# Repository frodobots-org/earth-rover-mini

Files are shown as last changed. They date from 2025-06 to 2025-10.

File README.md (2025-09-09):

<p align="center">
  Earth Rovers SDK Logo
  <h3 align="center">Frodobots AI</h3>
  <br>
</p>

# EarthRover Mini+

 

# Buy the Robot
- [Shopify](https://shop.frodobots.com/collections/earth-rovers/products/earth-rover-mini-plus)
  
# Getting Started

Core Development is done in two sections under Software
- [Software Development](/Software)
- [Host User Development](/Software/linux)
- [Client Side(EarthRover Mini) Development](/Software/STM32/applications)

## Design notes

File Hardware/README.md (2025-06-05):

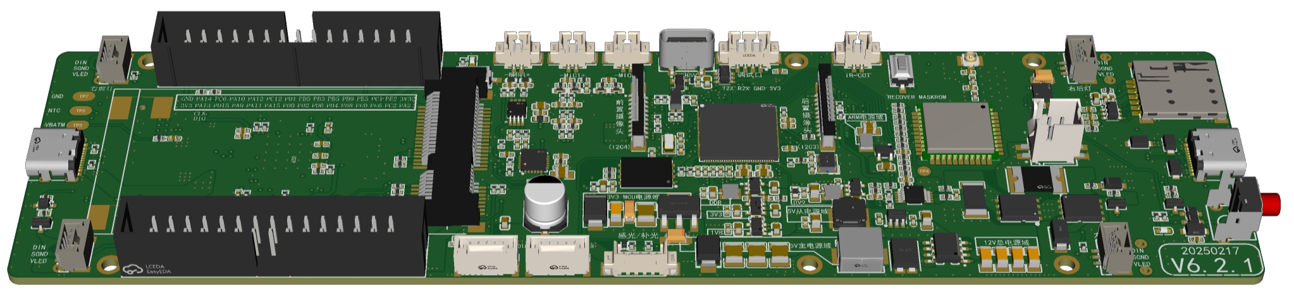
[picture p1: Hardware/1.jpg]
PCB1

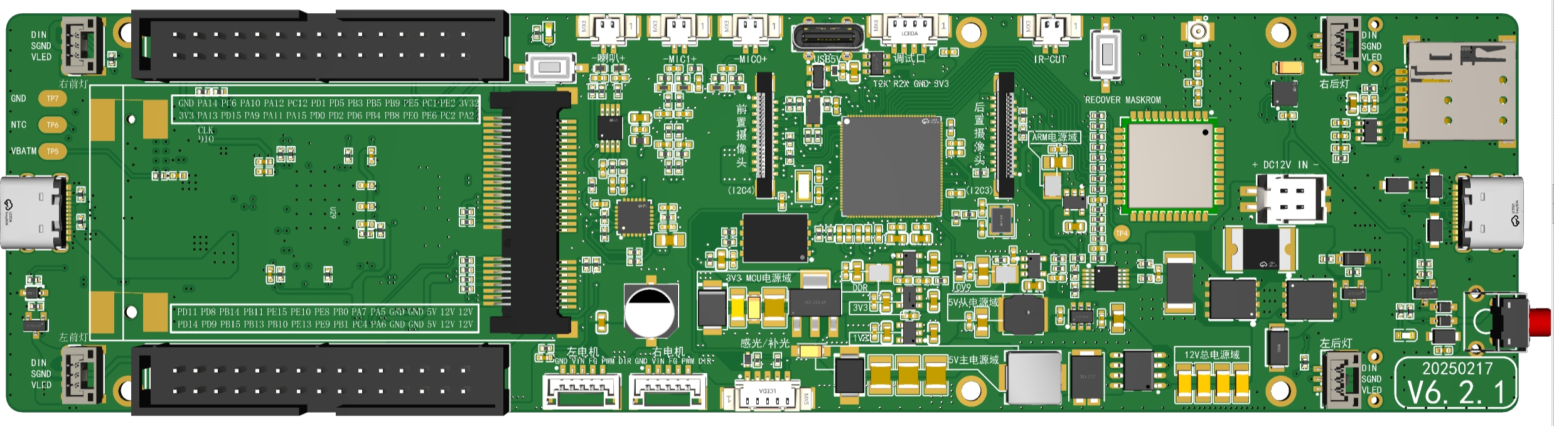
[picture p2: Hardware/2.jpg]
PCB2

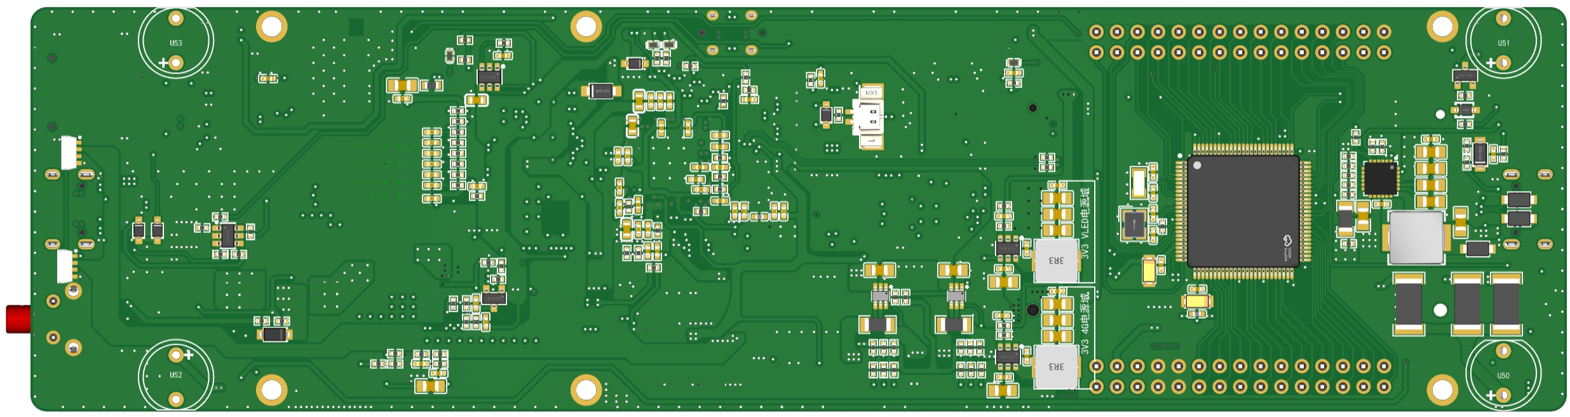
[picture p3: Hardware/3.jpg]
PCB3


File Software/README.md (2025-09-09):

# Specification
| | Specification |
|---|---|
| **Host** | RV1106G3 |
| **RAM (DDR)** | 256MB |
| **Flash (Nand)** | 128MB |
| **Operating System (Host)** | Linux |
| **Client** | STM32F407 |
| **Operating System (Client)** | RT-Thread |
| **Battery Type** | 18650 |
| **Battery Capacity** | 6000mAh |

# Block Diagram


# Core Architecture

The firmware is built on a **multi-threaded architecture**, where dedicated tasks handle specific subsystems.  
This concurrent design ensures that critical operations like **motor control** and **sensor processing** are not blocked by lower-priority tasks like communication.

The main threads are orchestrated in `applications/main.c`, which acts as the system's entry point.

## Key Threads

- **Main Thread (`main.c`)**  
  - Initializes all hardware peripherals and application threads.  
  - Enters a loop that manages system-level state (e.g., controlling LEDs for charging, running, error).

- **IMU Thread (`imu.c`)**  
  - Manages the Inertial Measurement Unit (MPU6050 + Magnetometer).  
  - Reads sensor data, performs sensor fusion, and handles calibration.

- **State Thread (`state.c`)**  
  - Handles robot power and operational logic.  
  - Monitors battery voltage/current, manages power sequences, and tracks system state.

- **Motor Thread (`motor.c`)**  
  - Translates desired speed/steering into PWM signals for motor drivers.

- **UART Threads (`uart_mutex.c`)**  
  - One thread listens for incoming commands.  
  - Another sends telemetry back to the host.

- **Control Loop Timer (`hwtimer.c`)**  
  - Provides a high-precision tick for the closed-loop motion control system.  
  - Runs PID calculations at a fixed rate.

---

# Important Files and Interactions

The system is divided into key modules that interact to achieve the robot’s functionality.

## 1. System Entry and State Management

- **`applications/main.c`**  
  - Initializes hardware, creates RTOS threads, and starts the scheduler.  
  - `main()`: Manages RGB status LEDs (charging, running, low battery).  

- **`applications/state.c`**  
  - Handles robot power state and operational mode.  
  - `state_thread_entry()`: Monitors battery (INA226), charger connection, and updates `robot_state`.  
  - `robot_power_on()` / `robot_power_off()`: Control physical power supply.  
  - `key_isr()` & `key_detect_task()`: Detect button presses and long-press events.

---

## 2. Motion Control and Closed-Loop Feedback

The motion control system integrates the **hardware timer**, **PID controller**, and **motor driver**.

- **`applications/hwtimer.c`**  
  - Provides timing for the PID loop.  
  - `timeout_cb()`: Executes every tick (e.g., 10 ms), computes motor RPM, and updates PID outputs.

- **`applications/pid.c`**  
  - Implements PID controllers for speed and heading.  
  - `get_Inc_pid_result()`: Incremental PID for speed (RPM adjustment).  
  - `get_heading_pid_result()`: PID for heading correction (yaw).

- **`applications/motor.c`**  
  - Interfaces control logic with physical motors.  
  - `motor_thread_entry()`: Main loop applying PID outputs.  
  - `motor_get_duty()`: Converts speed/steer commands to duty cycles.  
  - `motor_move_forward()`, `motor_move_backward()`, etc.: Handle motor direction and PWM updates.

---

## 3. Sensor Fusion and Orientation

The IMU subsystem provides stable orientation estimates using the MPU6050 and magnetometer.

- **`applications/imu.c`**  
  - `imu_thread_entry()`: Reads sensors, manages calibration, runs sensor fusion.  
  - `IMUupdate()` / `IMUupdate_dmp()`: Compute pitch, roll, and yaw.  
  - `MPU_6050_Calibrate()` / `QMC5883L_Calibrate()`: Handle calibration routines.

- **`applications/MPU6050_DMP/`**  
  - Contains InvenSense MPU6050 motion driver.  
  - `inv_mpu_dmp_motion_driver.c`: Loads/configures DMP firmware.  
  - `dmp_read_fifo()`: Reads quaternion data from FIFO.

---

## 4. Communication Protocol

External communication uses a **custom UART protocol (UCP)**.

- **`applications/ucp.h`**  
  - Defines UART Control Protocol (UCP).  
  - Contains command IDs (e.g., `UCP_MOTOR_CTL`, `UCP_RPM_REPORT`) and packet structures.

- **`applications/uart_mutex.c`**  
  - Implements thread-safe UART communication using mutexes.  
  - `uart_thread_entry()`: Receives and parses incoming data packets (CRC check, command handling).  
  - `uart_send_thread_entry()`: Periodically sends telemetry (RPM, battery, IMU orientation).  

---

# Development
- **Host**: 🖥 [Learn more here](../Software/Linux)
- **Client**: ⚙ [Learn more here](http://example.com/stm32f407)

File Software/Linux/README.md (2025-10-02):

# Earth Rover Mini+ Host Development

## Build Example
```
git clone --recursive https://github.com/frodobots-org/earth-rover-mini.git
cd earth-rover-mini/Software/Linux
mkdir build
cd build
cmake -DCMAKE_TOOLCHAIN_FILE=../toolchain.cmake ..
make
```

## Connect to Robot
- Install ADB on your development platform
- Search and connect the wireless network <b>frodobot_xxx</b>. The default password is <b>12345678</b>.
- Once the connection is established. Connect to your robot with adb
```bash
adb connect 192.168.11.1
adb shell
```

# Host Control Instructions

This section provides instructions on how to control the robot from a host computer for development and testing purposes.

---

## Control Mechanism

The robot is controlled via a **serial interface** using the custom **UART Control Protocol (UCP)** defined in `applications/ucp.h`.  
By sending formatted data packets to the robot's `uart3` port, you can:

- Control movement  
- Trigger calibration routines  
- Receive telemetry  

---

## Serial Port Settings

- **Baud Rate:** 115200  
- **Data Bits:** 8  
- **Parity:** None  
- **Stop Bits:** 1  

---

## Teleoperation (Manual Control)

To manually control the robot, send **`UCP_MOTOR_CTL` (ID: 0x02)** packets.  
These packets contain the desired **linear** and **angular velocity**.

---

## Control Packet Structure (`ucp_ctl_cmd_t`)

The command packet is composed of a **header**, a **payload**, and a **CRC checksum**.  
The **motor control payload** is defined as follows:

| Field | Type | Description |
|---|---|---|
| `hd` | `ucp_hd_t`| UCP Header (contains length, ID=0x02, index) |
| `speed` | `int16_t` | Desired linear velocity. Positive = forward, negative = backward. Range: -100 to 100. |
| `angular` | `int16_t` | Desired angular velocity. Positive = right, negative = left. Range: -100 to 100. |
| `front_led` | `int16_t` | Controls the front LEDs (not fully implemented). |
| `back_led`  | `int16_t` | Controls the back LEDs (not fully implemented). |
| `...` | `...` | Reserved fields. |

---

## Getting Started: A Simple Teleop Example

Look to `src/examples/move.cpp`

# Camera Example

## Getting Started: Dual Camera Streaming Over RTSP

Look to `src/Examples/sample_demo_dual_camera.c`
#### Run the example code on the Earth Rover Mini
- Build Examples
- Push `sample_demo_dual_camera` to device via ADB
```
adb push sample_demo_dual_camera /tmp/
```
- Run example
```
adb shell /tmp/sample_demo_dual_camera -s 0 -W 1920 -H 1080 -w 720 -h 576 -f 30 -r 0 -s 1 -W 1920 -H 1080 -w 720 -h 576 -f 30 -r 0 -n 1 -b 1
```
#### Capture video from the Earth Rover Mini camera on the computer
- Connect with Earth Rover Mini with same local network.
- Use Python Opencv
```python
import cv2
'''
rtsp://<Earth Rover Mini IP>/live/0  Front camera main-stream
rtsp://<Earth Rover Mini IP>/live/1  Front camera sub-stream
rtsp://<Earth Rover Mini IP>/live/2  Rear camera main-stream
rtsp://<Earth Rover Mini IP>/live/3  Rear camera sub-stream
'''
cap = cv2.VideoCapture("rtsp://<Earth Rover Mini IP>/live/0")
if not cap.isOpened():
    print("Failed to open RTSP stream")
    exit()
while True:
    ret, frame = cap.read()
    if not ret:
        print("Failed to read frame")
        break
    cv2.imshow("RTSP Stream", frame)
    if cv2.waitKey(1) & 0xFF == ord("q"):
        break

cap.release()
cv2.destroyAllWindows()
```

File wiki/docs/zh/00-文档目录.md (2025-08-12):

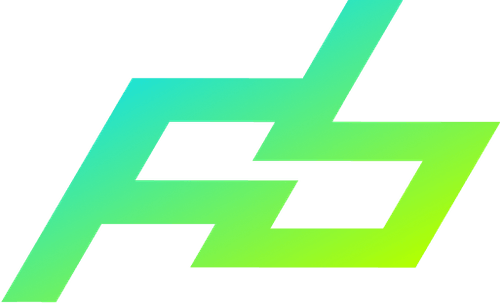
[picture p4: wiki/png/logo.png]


# 00-文档目录

## 1 组装与烧录

## 2 在Discord驾驶

## 3 登录机器

* adb 工具安装
* ssh 工具安装
* 通过adb访问机器
* 通过ssh访问机器 

## 4 在机器上运行程序

* 交叉编译
* 开机启动

## 5 STM32 功能开发

* **5.1 电机控制**
* **5.2 指示灯控制**
* **5.3 车灯控制**
* **5.4 电池容量**
* **5.5 IMU**
  * IMU 校准
  * IMU 数据获取

## 6 RV1106 功能开发

* **6.1 4G 模组入网与退网**
* **6.2 WIFI 模组入网与退网**
* **6.3 GPS 定位获取**
* **6.4  音视频媒体数据采集**
* **6.5 机器 web 页面**

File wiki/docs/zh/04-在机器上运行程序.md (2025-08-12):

# 04-在机器上运行程序

## 4.1 交叉编译

* 参考文档 [Readme](https://github.com/frodobots-org/earth-rover-mini/blob/dev/Software/Linux/README.md)

## 4.2 开启程序开机自启动

> 开发者可将/usr/bin/frodobot.bin 替换为自己编译后的程序

```shell
root@frodobot_j61grz:$ cat /usr/bin/frodobot.sh 
#!/bin/sh

#/usr/bin/frodobot-uart /dev/ttyS4

echo "frodobot-uart app exit."

while true; do
  /usr/bin/frodobot.bin
  echo "Exit frodobot. Sleep 5 sec..."
  sleep 5
done
```

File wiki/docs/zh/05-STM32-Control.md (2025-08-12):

# 05-STM32-Control
## 简介

* RV1106&STM32通信原理
RV1106与STM32的通信协议包构成为<hd><data><ccr>，以下是详细介绍：
* 协议头
```c
typedef struct ucp_hd {
    uint16_t    len; 
    uint8_t     id;
    uint8_t     index;
} ucp_hd_t __attribute__((packed));
```
RV1106&STM32的协议包头构成如上结构体的成员部分，<0xfd 0xff>、len-协议包字节长度、id-协议包id号、index-包序号，共6个字节长度。

* 协议尾
RV1106&STM32的协议包尾构成为CRC16校验位，共2个字节长度(CRC（循环冗余校验，Cyclic Redundancy Check）是一种常见的用于检测数据传输或存储错误的校验方式。它通过多项式运算，将数据映射为一个固定长度的校验码)，最终得到2个字节长度校验码<crc1 crc2>，以下代码块为两个校验查表数组以及校验算法部分。
```c
static uint8_t crc_hi_table [ ] = { 0x00 , 0xC1 , 0x81 , 0x40 , 0x01 , 0xC0 , 0x80 , 0x41 , 0x01 , 0xC0 , 0x80 , 0x41 ,
        0x00 , 0xC1 , 0x81 , 0x40 , 0x01 , 0xC0 , 0x80 , 0x41 , 0x00 , 0xC1 , 0x81 , 0x40 , 0x00 , 0xC1 , 0x81 ,
        0x40 , 0x01 , 0xC0 , 0x80 , 0x41 , 0x01 , 0xC0 , 0x80 , 0x41 , 0x00 , 0xC1 , 0x81 , 0x40 , 0x00 , 0xC1 ,
        0x81 , 0x40 , 0x01 , 0xC0 , 0x80 , 0x41 , 0x00 , 0xC1 , 0x81 , 0x40 , 0x01 , 0xC0 , 0x80 , 0x41 , 0x01 ,
        0xC0 , 0x80 , 0x41 , 0x00 , 0xC1 , 0x81 , 0x40 , 0x01 , 0xC0 , 0x80 , 0x41 , 0x00 , 0xC1 , 0x81 , 0x40 ,
        0x00 , 0xC1 , 0x81 , 0x40 , 0x01 , 0xC0 , 0x80 , 0x41 , 0x00 , 0xC1 , 0x81 , 0x40 , 0x01 , 0xC0 , 0x80 ,
        0x41 , 0x01 , 0xC0 , 0x80 , 0x41 , 0x00 , 0xC1 , 0x81 , 0x40 , 0x00 , 0xC1 , 0x81 , 0x40 , 0x01 , 0xC0 ,
        0x80 , 0x41 , 0x01 , 0xC0 , 0x80 , 0x41 , 0x00 , 0xC1 , 0x81 , 0x40 , 0x01 , 0xC0 , 0x80 , 0x41 , 0x00 ,
        0xC1 , 0x81 , 0x40 , 0x00 , 0xC1 , 0x81 , 0x40 , 0x01 , 0xC0 , 0x80 , 0x41 , 0x01 , 0xC0 , 0x80 , 0x41 ,
        0x00 , 0xC1 , 0x81 , 0x40 , 0x00 , 0xC1 , 0x81 , 0x40 , 0x01 , 0xC0 , 0x80 , 0x41 , 0x00 , 0xC1 , 0x81 ,
        0x40 , 0x01 , 0xC0 , 0x80 , 0x41 , 0x01 , 0xC0 , 0x80 , 0x41 , 0x00 , 0xC1 , 0x81 , 0x40 , 0x00 , 0xC1 ,
        0x81 , 0x40 , 0x01 , 0xC0 , 0x80 , 0x41 , 0x01 , 0xC0 , 0x80 , 0x41 , 0x00 , 0xC1 , 0x81 , 0x40 , 0x01 ,
        0xC0 , 0x80 , 0x41 , 0x00 , 0xC1 , 0x81 , 0x40 , 0x00 , 0xC1 , 0x81 , 0x40 , 0x01 , 0xC0 , 0x80 , 0x41 ,
        0x00 , 0xC1 , 0x81 , 0x40 , 0x01 , 0xC0 , 0x80 , 0x41 , 0x01 , 0xC0 , 0x80 , 0x41 , 0x00 , 0xC1 , 0x81 ,
        0x40 , 0x01 , 0xC0 , 0x80 , 0x41 , 0x00 , 0xC1 , 0x81 , 0x40 , 0x00 , 0xC1 , 0x81 , 0x40 , 0x01 , 0xC0 ,
        0x80 , 0x41 , 0x01 , 0xC0 , 0x80 , 0x41 , 0x00 , 0xC1 , 0x81 , 0x40 , 0x00 , 0xC1 , 0x81 , 0x40 , 0x01 ,
        0xC0 , 0x80 , 0x41 , 0x00 , 0xC1 , 0x81 , 0x40 , 0x01 , 0xC0 , 0x80 , 0x41 , 0x01 , 0xC0 , 0x80 , 0x41 ,
        0x00 , 0xC1 , 0x81 , 0x40 };

static uint8_t crc_lo_table [ ] = { 0x00 , 0xC0 , 0xC1 , 0x01 , 0xC3 , 0x03 , 0x02 , 0xC2 , 0xC6 , 0x06 , 0x07 , 0xC7 ,
        0x05 , 0xC5 , 0xC4 , 0x04 , 0xCC , 0x0C , 0x0D , 0xCD , 0x0F , 0xCF , 0xCE , 0x0E , 0x0A , 0xCA , 0xCB ,
        0x0B , 0xC9 , 0x09 , 0x08 , 0xC8 , 0xD8 , 0x18 , 0x19 , 0xD9 , 0x1B , 0xDB , 0xDA , 0x1A , 0x1E , 0xDE ,
        0xDF , 0x1F , 0xDD , 0x1D , 0x1C , 0xDC , 0x14 , 0xD4 , 0xD5 , 0x15 , 0xD7 , 0x17 , 0x16 , 0xD6 , 0xD2 ,
        0x12 , 0x13 , 0xD3 , 0x11 , 0xD1 , 0xD0 , 0x10 , 0xF0 , 0x30 , 0x31 , 0xF1 , 0x33 , 0xF3 , 0xF2 , 0x32 ,
        0x36 , 0xF6 , 0xF7 , 0x37 , 0xF5 , 0x35 , 0x34 , 0xF4 , 0x3C , 0xFC , 0xFD , 0x3D , 0xFF , 0x3F , 0x3E ,
        0xFE , 0xFA , 0x3A , 0x3B , 0xFB , 0x39 , 0xF9 , 0xF8 , 0x38 , 0x28 , 0xE8 , 0xE9 , 0x29 , 0xEB , 0x2B ,
        0x2A , 0xEA , 0xEE , 0x2E , 0x2F , 0xEF , 0x2D , 0xED , 0xEC , 0x2C , 0xE4 , 0x24 , 0x25 , 0xE5 , 0x27 ,
        0xE7 , 0xE6 , 0x26 , 0x22 , 0xE2 , 0xE3 , 0x23 , 0xE1 , 0x21 , 0x20 , 0xE0 , 0xA0 , 0x60 , 0x61 , 0xA1 ,
        0x63 , 0xA3 , 0xA2 , 0x62 , 0x66 , 0xA6 , 0xA7 , 0x67 , 0xA5 , 0x65 , 0x64 , 0xA4 , 0x6C , 0xAC , 0xAD ,
        0x6D , 0xAF , 0x6F , 0x6E , 0xAE , 0xAA , 0x6A , 0x6B , 0xAB , 0x69 , 0xA9 , 0xA8 , 0x68 , 0x78 , 0xB8 ,
        0xB9 , 0x79 , 0xBB , 0x7B , 0x7A , 0xBA , 0xBE , 0x7E , 0x7F , 0xBF , 0x7D , 0xBD , 0xBC , 0x7C , 0xB4 ,
        0x74 , 0x75 , 0xB5 , 0x77 , 0xB7 , 0xB6 , 0x76 , 0x72 , 0xB2 , 0xB3 , 0x73 , 0xB1 , 0x71 , 0x70 , 0xB0 ,
        0x50 , 0x90 , 0x91 , 0x51 , 0x93 , 0x53 , 0x52 , 0x92 , 0x96 , 0x56 , 0x57 , 0x97 , 0x55 , 0x95 , 0x94 ,
        0x54 , 0x9C , 0x5C , 0x5D , 0x9D , 0x5F , 0x9F , 0x9E , 0x5E , 0x5A , 0x9A , 0x9B , 0x5B , 0x99 , 0x59 ,
        0x58 , 0x98 , 0x88 , 0x48 , 0x49 , 0x89 , 0x4B , 0x8B , 0x8A , 0x4A , 0x4E , 0x8E , 0x8F , 0x4F , 0x8D ,
        0x4D , 0x4C , 0x8C , 0x44 , 0x84 , 0x85 , 0x45 , 0x87 , 0x47 , 0x46 , 0x86 , 0x82 , 0x42 , 0x43 , 0x83 ,
        0x41 , 0x81 , 0x80 , 0x40 };

static uint16_t crc16 ( char* msg , size_t len )
{
    uint8_t crc_hi = 0xFF;
    uint8_t crc_lo = 0xFF;
    uint8_t index;

    while ( len-- )
    {
        index = crc_lo ^ *msg++;
        crc_lo = crc_hi ^ crc_hi_table [ index ];
        crc_hi = crc_lo_table [ index ];
    }
    return (crc_hi << 8 | crc_lo);
}
```

* RV1106&STM32心跳包-01解析
RV1106可以通过ping包获取STM32的运行状态，以下是心跳包的组成结构
RV1106：
```c
typedef struct ucp_alive_ping {
    ucp_hd_t    hd;
} ucp_alive_ping_t __attribute__((packed));
```
RV1106的ping包组成十分简单，数据段部分是没有的，仅由一个包头包尾构成
ping包组成结构：<0xfd 0xff><hd><crc>

STM32：
```c
typedef struct ucp_alive_pong {
    ucp_hd_t    hd;
    uint8_t     err;
} ucp_alive_pong_t __attribute__((packed));
```
STM32的pong包组成相比RV1106的ping包的数据段多了一个错误码，以此反映STM32的运行状态，当错误码err = 0时，代表通信正常，err = 1则通信异常
pong包组成结构：<0xfd 0xff><hd><err><crc>

## 5.1 电机&车灯
* RV1106&STM32-控制协议包-02解析
RV1106：
```c
typedef struct ucp_ctl_cmd {
    ucp_hd_t    hd;
    int16_t     speed;
    int16_t     angular;
    int16_t     front_led;
    int16_t     back_led;
    uint16_t    version;
    uint16_t    reserve1;
    uint32_t    reserve2;
} ucp_ctl_cmd_t __attribute__((packed));
```
hd -> 包头（len-协议包字节长度、id-协议包id号、index-包序号）
speed -> 前进速度（speed > 0向前运动，speed < 0 向后运动，speed取值范围（-100 ~ 100））
angular-> 左右轮速差（angluar > 0向左运动，angluar < 0 向右运动，angluar取值范围（-100 ~ 100））
front_led-> 灯光控制（front_led = 100为开灯状态，front_led = 0为关灯状态）
back_led -> 保留位，暂不使用
version  -> 保留位，暂不使用
reserve1-> 保留位，暂不使用
reserve2 -> 保留位，暂不使用

* 电机控制
协议包组成：<0xfd 0xff><hd><speed><angular><......><crc>

* 车灯控制
协议包组成：<0xfd 0xff><hd><......><front_led><......><crc>

## 5.2 系统状态灯
* RV1106&STM32-状态灯控制协议包-0A解析
RV1106：
```c
typedef struct ucp_led_status {
    ucp_hd_t    hd;
    ucp_state_e status;
}
```
hd-> 包头（len-协议包字节长度、id-协议包id号、index-包序号）
status-> RV1106联网状态（详细见以下枚举）

```c
typedef enum ucp_state_e {
        UCP_STATE_UNKNOWN = 0,       //初始状态
        UCP_STATE_SIMABSENT = 1,     //SIM检测中 
        UCP_NETWORK_DISCONNECTED,    //联网失败
        UCP_NETWORK_CONNECTED,       //联网成功
} ucp_state_e;
```
* 状态灯控制
状态灯控制协议包组成结构：<0xfd 0xff><hd><status><crc>
## 5.4 系统电源
* RV1106&STM32-回传协议包-05解析
该协议包STM32自动上报RV1106,每20ms发送一包
STM32：
```c
typedef struct ucp_rep { //report
    ucp_hd_t    hd;
    uint16_t    battery;
    int16_t     rpm[4];
    uint8_t     power;
    uint8_t     voltage;
    uint16_t    current;
    int16_t     acc[3];
    int16_t     gyros[3];
    int16_t     mag[3];
    int16_t     heading;
} ucp_rep_t __attribute__((packed));
```
hd              -> 包头（len-协议包字节长度、id-协议包id号、index-包序号）
battery         -> 电池电量百分比（battery取值范围（-100 ~ 100））
power           -> 系统功率（W）
voltage         -> 系统电压（10 * V）
current         -> 系统电流（100 * A）

* 电源数据读取示例
## 5.5 IMU
### 5.5.1 IMU校准
* RV1106&STM32-IMU校准协议包-03解析

* RV1106&STM32-IMU校准协议包-04解析

### 5.5.2 IMU数据获取
* RV1106&STM32-回传协议包-05解析

### 5.5.3 保存校准数据
* RV1106&STM32-IMU校准回传协议包-06解析

* RV1106&STM32-IMU校准回传协议包-07解析

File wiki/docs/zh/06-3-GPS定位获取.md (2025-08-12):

# 06-3 GPS定位获取

**Miniplus GPS 模组使用 Quectel LC29HDA, 支持双频、RTK解算、开阔环境精度达到厘米级别**

> 室内以及遮挡严重区域无法获得GPS定位

## 1 LC29H GPS 模组

* 串口波特率 115200
* 串口输入输出语句符合 [NMEA0183 ](https://en.wikipedia.org/wiki/NMEA_0183)格式

## 2 打开GPS输出

* NMEA1083 语句校验

  ```c++
  #include <ostream>
  #include <iostream>
  #include <iomanip>
  #include <sstream>
  
  static unsigned char calculateChecksum(const std::string& sentence) {
      unsigned char checksum = 0;
      for (size_t i = 1; i < sentence.size() && sentence[i] != '*'; ++i) {
          checksum ^= sentence[i];
      }
      return checksum;
  }
  
  static std::string constructNMEASentence(const std::string& baseSentence) {
      unsigned char checksum = calculateChecksum(baseSentence);
      std::ostringstream oss;
      oss << baseSentence << '*' << std::uppercase << std::hex << std::setw(2) << std::setfill('0') << static_cast<int>(checksum) << "\r\n";
      return oss.str();
  }
  ```

* 设置GPS语句输出频率

  ```c++
  int lc29h::Init()
  {
          if (!this->Probe()) { //探测串口设备是否存在
                  std::cout << "Probe failed.\n";
                  return -1;
          }
  
          this->Open(); //打开串口设备
  
          this->Write(constructNMEASentence("$PQTMVERNO")); //查询版本号
          std::string line;
          this->Read(line);
          if (line.empty()) {
                  SPDLOG_WARN("LC29H is not exsit.");
                  return -1;
          }
  
          SPDLOG_INFO("LC29H Version {} ", line);
  
      	//输出频率最高支持20HZ
          this->Write(constructNMEASentence("$PQTMCFGMSGRATE,W,GSV,1")); //以1HZ 频率输出GSV语句
          this->Write(constructNMEASentence("$PQTMCFGMSGRATE,W,RMC,1")); //以1HZ 频率输出RMC语句
          this->Write(constructNMEASentence("$PQTMCFGMSGRATE,W,GSA,0")); //关闭GSA语句输出
          this->Write(constructNMEASentence("$PQTMCFGMSGRATE,W,GLL,0")); //关闭GLL语句输出
          this->Write(constructNMEASentence("$PQTMCFGMSGRATE,W,VTG,0")); //关闭VTG语句输出
          this->Write(constructNMEASentence("$PQTMCFGMSGRATE,W,GGA,1")); //以1HZ 频率输出GGA语句
  
          std::cout << "lc29h Init done." << std::endl;
          exit_ = false;
  
          return 0;
  }
  ```

## 2 解析GPS语句

**串口输入输出语句符合 [NMEA0183 ](https://en.wikipedia.org/wiki/NMEA_0183)格式, 可使用开源库[minmea](https://github.com/kosma/minmea) 解析NMEA0183语句, 读取串口以获取GPS定位语句**

```c++
void Ec2x::ParseNmeaSentence(std::string sentence) {
        static float rmc_speed = 0;
        static int rmc_ttff = 0;
        static bool last_sentence_is_gsv = false;
        switch(minmea_sentence_id(sentence.c_str(), false)) {
        case MINMEA_SENTENCE_GGA: {
                struct minmea_sentence_gga frame;
                if (minmea_parse_gga(&frame, sentence.c_str())) {
                        float longitude = minmea_tocoord(&frame.longitude);
                        float latitude = minmea_tocoord(&frame.latitude);
                        float hdop = minmea_tocoord(&frame.hdop);
                        float altitude = minmea_tocoord(&frame.altitude);
                        //SPDLOG_INFO("longitude {} latitude {} hdop {} altitude {} fix_quality {}",ongitude, latitude, hdop, altitude, frame.fix_quality);
                }
        } break;
        default: {
        } break;
        }
}
```

## 3 使用RTK服务实现厘米级定位

**LC29HDA模组支持直接输入RTCM3语句辅助GPS位置解算，提高定位精度**

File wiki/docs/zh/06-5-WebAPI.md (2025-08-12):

# 06-5 Web API

**机器提供系列HTTP API 做访问及控制**

### 1 4G入网配置

### 2 WIFI入网配置

### 3 流媒体配置

### 4 电机控制

### 5 IMU 矫正及数据收集

### 6 GPS数据收集

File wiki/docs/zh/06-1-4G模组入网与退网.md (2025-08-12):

# 06-1 4G模组入网与退网

1. **检查模组插入状态**

   1. 开机过程中出现或者输入 dmesg 指令查看，出现下方日志证明4G模组正确插入

      ```shell
      [  378.744099] usb 1-1.1: new high-speed USB device number 5 using xhci-hcd
      [  378.913481] option 1-1.1:1.0: GSM modem (1-port) converter detected
      [  378.914580] usb 1-1.1: GSM modem (1-port) converter now attached to ttyUSB0
      [  378.915026] option 1-1.1:1.1: GSM modem (1-port) converter detected
      [  378.916713] usb 1-1.1: GSM modem (1-port) converter now attached to ttyUSB1
      [  378.917208] option 1-1.1:1.2: GSM modem (1-port) converter detected
      [  378.918934] usb 1-1.1: GSM modem (1-port) converter now attached to ttyUSB2
      [  378.919423] option 1-1.1:1.3: GSM modem (1-port) converter detected
      [  378.921144] usb 1-1.1: GSM modem (1-port) converter now attached to ttyUSB3
      [  378.945926] qmi_wwan_q 1-1.1:1.4: cdc-wdm0: USB WDM device
      [  378.947713] qmi_wwan_q 1-1.1:1.4: Quectel EG25-G work on RawIP mode
      [  378.948779] qmi_wwan_q 1-1.1:1.4: rx_urb_size = 1520
      [  378.949272] qmi_wwan_q 1-1.1:1.4 wwan0: register 'qmi_wwan_q' at usb-xhci-hcd.0.auto-1.1, WWAN/QMI device, a6:02:08:ff:40:7d
      ```

   2. 出现下方日志证明4G模组被中途拔出，需要检查。

      ```shell
      [  364.896693] usb 1-1.1: USB disconnect, device number 4
      [  364.897175] option1 ttyUSB0: GSM modem (1-port) converter now disconnected from ttyUSB0
      [  364.897251] option 1-1.1:1.0: device disconnected
      [  364.899374] option1 ttyUSB1: GSM modem (1-port) converter now disconnected from ttyUSB1
      [  364.899462] option 1-1.1:1.1: device disconnected
      [  364.899932] option1 ttyUSB2: GSM modem (1-port) converter now disconnected from ttyUSB2
      [  364.900006] option 1-1.1:1.2: device disconnected
      [  364.900819] option1 ttyUSB3: GSM modem (1-port) converter now disconnected from ttyUSB3
      [  364.900908] option 1-1.1:1.3: device disconnected
      [  364.901168] qmi_wwan_q 1-1.1:1.4 wwan0: unregister 'qmi_wwan_q' usb-xhci-hcd.0.auto-1.1, WWAN/QMI device
      ```

   3. 运行过程中出现下列日志说明4G模组未正确插入。

      ```shell
      [06-23_07:12:26:076] Quectel_QConnectManager_Linux_V1.6.0.24
      [06-23_07:12:26:078] network interface '' or qmidev '' is not exist
      [06-23_07:12:26:078] qmidevice_detect failed
      [06-23_07:12:26:078] qmidevice_detect failed
      ```

2. **注网程序**

   > quectel-CM 是移远官方提供用来拨号注网的程序，系统会自动运行拨号程序，如果需要手动尝试，请先停止掉启动脚本和quectel-CM拨号程序

   1. 自启动脚本

      > quectel.sh 自启动脚本用做参数化开机启动和保活quectel-CM 入网程序

      ```shell
      root@frodobot_j61grz:$ cat /usr/bin/quectel.sh 
      #!/bin/sh
      
      while true; do
        ARGS=$(cat /userdata/lte.env)
        /usr/bin/quectel-CM $ARGS
        sleep 5
      done
      ```

   2. quectel-CM 参数介绍

      > 通常在国内无需设置任何运行参数，直接运行quectel-CM 进程即可。

      ```shell
      [06-23_04:32:27:609] Quectel_QConnectManager_Linux_V1.6.0.24
      [06-23_04:32:27:609] Usage: quectel-CM [options]
      [06-23_04:32:27:609] -s [apn [user password auth]]          Set apn/user/password/auth get from your network provider. auth: 1~pap, 2~chap
      [06-23_04:32:27:609] -p pincode                             Verify sim card pin if sim card is locked
      [06-23_04:32:27:609] -p [quectel-][qmi|mbim]-proxy          Request to use proxy
      [06-23_04:32:27:609] -f logfilename                         Save log message of this program to file
      [06-23_04:32:27:609] -u usbmonlog filename                  Save usbmon log to file
      [06-23_04:32:27:609] -i interface                           Specify which network interface to setup data call when multi-modems exits
      [06-23_04:32:27:609] -4                                     Setup IPv4 data call (default)
      [06-23_04:32:27:609] -6                                     Setup IPv6 data call
      [06-23_04:32:27:609] -n pdn                                 Specify which pdn to setup data call (default 1 for QMI, 0 for MBIM)
      [06-23_04:32:27:609] -k pdn                                 Specify which pdn to hangup data call (by send SIGINT to 'quectel-CM -n pdn')
      [06-23_04:32:27:609] -m iface-idx                           Bind QMI data call to wwan0_<iface idx> when QMAP used. E.g '-n 7 -m 1' bind pdn-7 data call to wwan0_1
      [06-23_04:32:27:609] -b                                     Enable network interface bridge function (default 0)
      [06-23_04:32:27:609] -v                                     Verbose log mode, for debug purpose.
      [06-23_04:32:27:609] [Examples]
      [06-23_04:32:27:610] Example 1: quectel-CM 
      [06-23_04:32:27:610] Example 2: quectel-CM -s 3gnet 
      [06-23_04:32:27:610] Example 3: quectel-CM -s 3gnet carl 1234 1 -p 1234 -f gobinet_log.txt
      ```

   3. SIM卡插入状态

      1. SIM 卡未插入 (SIMStatus : SIM_ABSENT)

         ```shell
         [01-01_15:09:17:488] Get clientWDS = 17
         [01-01_15:09:17:531] Get clientDMS = 1
         [01-01_15:09:17:554] Get clientNAS = 2
         [01-01_15:09:17:581] Get clientUIM = 2
         [01-01_15:09:17:620] Get clientWDA = 1
         [01-01_15:09:17:649] requestBaseBandVersion EG25GGBR07A08M2G
         [01-01_15:09:17:779] requestGetSIMStatus SIMStatus: SIM_ABSENT
         [01-01_15:09:17:808] requestGetProfile[1] CTNET///0
         [01-01_15:09:17:848] requestRegistrationState2 MCC: 0, MNC: 0, PS: Detached, DataCap: UNKNOW
         [01-01_15:09:17:869] requestQueryDataCall IPv4ConnectionStatus: DISCONNECTED
         [01-01_15:09:17:869] ifconfig wwan0 0.0.0.0
         [01-01_15:09:17:908] ifconfig wwan0 down
         ```

      2. SIM卡插入，拨号入网成功

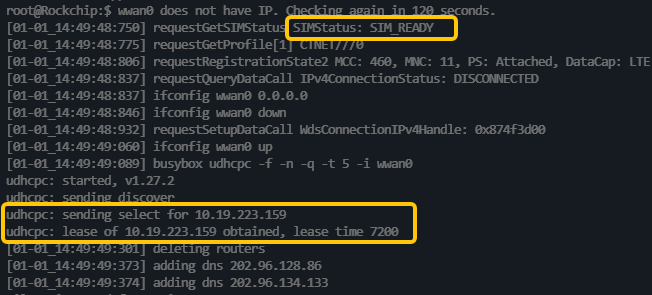
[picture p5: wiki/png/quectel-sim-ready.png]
         

         > **注意如果拨号成功仍然不能上网（使用ping 命令测试联网结果），则可能是SIM卡欠费或者流量异常。

         ``` shell
         ping frodobots.ai
         ```

   4. 查看联网状态

      * p2p0 为机器热点的固定IP地址。
      * wlan0 是机器的WIFI 网卡，成功连接路由器后在inet addr 一栏会得到一个点分十进制的局域网IP地址。
      * wwan0 是4G网卡，成功连接基站后在inet addr 一栏会得到一个点分十进制的局域网IP地址。

      ```shell
      root@frodobot_j61grz:$ ifconfig
      lo        Link encap:Local Loopback  
                inet addr:127.0.0.1  Mask:255.0.0.0
                UP LOOPBACK RUNNING  MTU:65536  Metric:1
                RX packets:0 errors:0 dropped:0 overruns:0 frame:0
                TX packets:0 errors:0 dropped:0 overruns:0 carrier:0
                collisions:0 txqueuelen:1000 
                RX bytes:0 (0.0 B)  TX bytes:0 (0.0 B)
      
      p2p0      Link encap:Ethernet  HWaddr A6:E8:8D:D9:9B:26  
                inet addr:192.168.11.1  Bcast:192.168.11.255  Mask:255.255.255.0
                UP BROADCAST RUNNING MULTICAST  MTU:1500  Metric:1
                RX packets:0 errors:0 dropped:0 overruns:0 frame:0
                TX packets:0 errors:0 dropped:0 overruns:0 carrier:0
                collisions:0 txqueuelen:1000 
                RX bytes:0 (0.0 B)  TX bytes:0 (0.0 B)
      
      wlan0     Link encap:Ethernet  HWaddr A4:E8:8D:D9:9B:26  
                inet addr:192.168.1.41  Bcast:192.168.1.255  Mask:255.255.255.0
                UP BROADCAST MULTICAST  MTU:1500  Metric:1
                RX packets:1323 errors:0 dropped:790 overruns:0 frame:0
                TX packets:95 errors:0 dropped:0 overruns:0 carrier:0
                collisions:0 txqueuelen:1000 
                RX bytes:190031 (185.5 KiB)  TX bytes:24235 (23.6 KiB)
      
      wwan0     Link encap:Ethernet  HWaddr A6:02:08:FF:40:7D  
                inet addr:10.7.189.65  Mask:255.255.255.252
                UP RUNNING NOARP  MTU:1500  Metric:1
                RX packets:2 errors:0 dropped:0 overruns:0 frame:0
                TX packets:2 errors:0 dropped:0 overruns:0 carrier:0
                collisions:0 txqueuelen:1000 
                RX bytes:612 (612.0 B)  TX bytes:656 (656.0 B)
      ```

3. 退网

   > 输入指令

   ```shell
   killall quectel.sh && killall quectel-CM
   或者是
   killall quectel.sh && ifconfig wwan0 down
   ```

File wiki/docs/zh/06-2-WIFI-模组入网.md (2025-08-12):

# 06-2 WIFI 模组入网

## 1  使用机器网页配网

* 手机连接机器热点(名称为 frodobot_xx)
* 打开手机浏览器进入网页 192.168.11.1

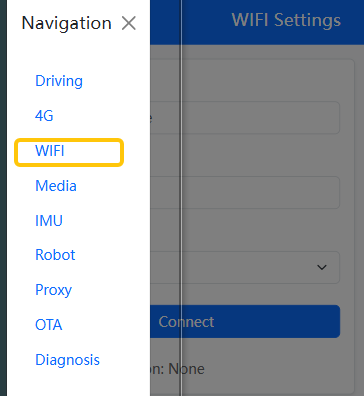
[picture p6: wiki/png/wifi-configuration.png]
	

* 输入SSID 和 PSK , 点击连接，15秒内应该建立WIFI连接

  > 如果是开放式WIFI，无需填写密码, Security Type 选择NONE

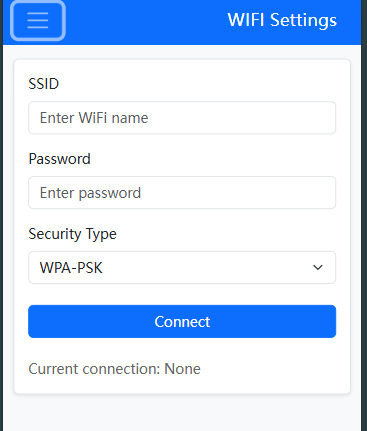
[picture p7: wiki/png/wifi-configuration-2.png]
	

## 2  手动修改WIFI 配置使用wpa_supplicant 工具配网

* 编辑配置文件

```shell
root@frodobot_j61grz:$ cat /userdata/wpa_supplicant.conf 
ctrl_interface=/var/run/wpa_supplicant
update_config=1
network={
    ssid="Frodobots"
    psk="11223344"
    key_mgmt=WPA-PSK
}
//如果是开放式WIFI, 密码不需要填写，key_mgmt=NONE
```

* 使用wpa_supplicant 工具连接WIFI

  > 连接前确保wpa_supplicant 进程没有在后台运行，如果有需要先停止掉wpa_supplicant 进程

```shell
killall wpa_supplicant
wpa_supplicant -B -iwlan0 -c /userdata/wpa_supplicant.conf
```

```shell
root@frodobot_j61grz:$ wpa_supplicant -B -iwlan0 -c /userdata/wpa_supplicant.con
f
Successfully initialized wpa_supplicant
rfkill: Cannot open RFKILL control device
root@frodobot_j61grz:$ wwan0 does not have IP. Checking again in 120 seconds.
[ 2301.645190] RTW: wlan0- hw port(1) mac_addr =a4:e8:8d:d9:9b:26
[ 2301.645471] RTW: p2p0- hw port(0) mac_addr =a6:e8:8d:d9:9b:26
[ 2301.661688] ========== ACS (VER-3) ==========
[ 2301.661715] Best 24G Channel:9
[ 2301.661728] Best 5G Channel:52
[ 2301.661728] 
[ 2301.669197] RTW: rtw_set_802_11_connect(wlan0)  fw_state=0x00000008
[ 2301.881953] RTW: start auth
[ 2301.885685] RTW: auth success, start assoc
[ 2301.904620] RTW: assoc success
[ 2301.910577] RTW: ============ STA [68:1b:ef:55:2a:20]  ===================
[ 2301.910618] RTW: mac_id : 2
[ 2301.910637] RTW: wireless_mode : 0x23
[ 2301.910655] RTW: mimo_type : 0
[ 2301.910672] RTW: static smps : N
[ 2301.910692] RTW: bw_mode : 20MHz, ra_bw_mode : 20MHz
[ 2301.910711] RTW: rate_id : 18
[ 2301.910730] RTW: rssi : -1 (%), rssi_level : 0
[ 2301.910750] RTW: is_support_sgi : Y, is_vht_enable : Y
[ 2301.910770] RTW: disable_ra : N, disable_pt : N
[ 2301.910788] RTW: is_noisy : N
[ 2301.910804] RTW: txrx_state : 0
[ 2301.910823] RTW: curr_tx_rate : CCK_1M (L)
[ 2301.910841] RTW: curr_tx_bw : 20MHz
[ 2301.910858] RTW: curr_retry_ratio : 0
[ 2301.910875] RTW: ra_mask : 0x00000000003fffff
[ 2301.910875] 
[ 2301.974511] RTW: recv eapol packet 1/4
[ 2301.976197] RTW: send eapol packet 2/4
[ 2302.015994] RTW: recv eapol packet 3/4
[ 2302.017327] RTW: send eapol packet 4/4
[ 2302.019276] RTW: set pairwise key camid:2, addr:68:1b:ef:55:2a:20, kid:0, type:AES
[ 2302.023181] RTW: set group key camid:3, addr:68:1b:ef:55:2a:20, kid:2, type:AES
```

* 使用udhcpc 工具获取IP地址

```shell
udhcpc -i wlan0
```

```shell
root@frodobot_j61grz:$ udhcpc -i wlan0
udhcpc: started, v1.27.2
udhcpc: sending discover

udhcpc: sending select for 192.168.1.41
udhcpc: lease of 192.168.1.41 obtained, lease time 259200
deleting routers
adding dns 192.168.1.1
```

## 3  断开WIFI网络

* 方式1 停止WIFI网卡

  ```shell
  ifconfig wlan0 down
  ```

* 方式2 输入一个错误的WIFI账号

* 方式3 停止wpa_supplicant 进程

  ```shell
  killall wpa_supplicant
  ```

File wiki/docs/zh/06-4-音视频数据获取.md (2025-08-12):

# 06-4 音视频数据获取

**机器提供HTTP API 来开启RTSP-Server 为客户端提供实时流媒体**

**基础信息**

- 接口域名：`http(s)://192.168.11.1/rtsp`
- 请求方式：POST
- 数据格式：JSON
- 认证方式：账户密码（HTTP Basic Auth）

## 1 开启RTSP流

> 接口URL

```shell
/start
```

**请求参数**

| 参数名 | 类型 | 是否必填 | 描述 |
| --- | --- | --- | --- |
| stream_id  | String | 是 | 流 ID，唯一标识 |
| resolution | String | 否 | 分辨率（如 "1080p"） |
| framerate  | Int | 否 | 帧率（默认 25） |
| bitrate | Int | 否 | 码率（Kbps） |

**请求示例**

```shell
curl -X POST \
  -u "username:password" \
  -H "Content-Type: application/json" \
  -d '{
    "stream_id": "camera001",
    "resolution": "720p",
    "framerate": 30,
    "bitrate": 2000
  }' \
  https://192.168.11.1/rtsp/start
```

**返回参数**

| 参数名 | 类型 | 描述 |
| --- | --- | --- |
| code | Int | 状态码（200 成功） |
| message | String | 提示信息 |
| rtsp_url  | String | RTSP 流地址 |
| expire_at | String | 流有效期（ISO 格式） |

**返回示例（成功）**

```json
{
  "code": 200,
  "message": "RTSP stream started successfully",
  "rtsp_url": "rtsp://192.168.11.1:554/camera001",
  "expire_at": "2025-06-24T12:00:00Z"
}
```

**返回示例（失败）**

```json
{
  "code": 401,
  "message": "Authentication failed"
}
```

## 2 关闭 RTSP 流

**接口 URL**

```plaintext
/stop
```

**请求参数**

| 参数名 | 类型 | 是否必填 | 描述 |
| --- | --- | --- | --- |
| stream_id | String | 是 | 流 ID，需关闭 |

**请求示例**

```shell
curl -X POST \
  -u "username:password" \
  -H "Content-Type: application/json" \
  -d '{
    "stream_id": "camera001"
  }' \
  https://api.example.com/rtsp/stop
```

**返回参数**

| 参数名  | 类型 | 描述 |
| --- | --- | --- |
| code | Int | 状态码（200 成功） |
| message | String | 提示信息 |

**返回示例（成功）**

```json
{
  "code": 200,
  "message": "RTSP stream stopped successfully"
}
```

## 3 错误码说明

| 错误码 | 描述 | 原因 |
| --- | --- | --- |
| 400 | Bad Request | 参数格式错误 |
| 401 | Unauthorized | 认证失败（账户 / 密码错误） |
| 403 | Forbidden | 权限不足 |
| 404 | Not Found | 流 ID 不存在 |
| 500 | Internal Server Error | 服务器内部错误 |

## 4 认证说明

- **方式**：HTTP Basic Authentication
- **示例**：在请求头中添加 `Authorization: Basic base64(username:password)`
- **生成工具**：可使用在线 Base64 编码工具生成认证头

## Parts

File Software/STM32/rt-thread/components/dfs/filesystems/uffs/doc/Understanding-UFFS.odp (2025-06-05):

## Understanding UFFS

Ricky Zheng

< ricky_gz_zheng@yahoo.co.nz >

Created: March 2007

Last modified: Nov 2011

## Content

- Why UFFS ?
- Design goal
- Flash: NOR vs NAND ?
- What's wrong with FAT ?
- UFFS basic idea
  - Serial number
  - Tree in memory
  - Journalizing
- UFFS architecture
  - UFFS device
  - Mount point
  - UFFS nodes tree
  - Mounting UFFS
  - Page spare/UFFS tags
  - Block info cache
  - UFFS page buffer
  - Block recover
  - Bad block management
  - How ECC works ?
  - Flash interface
- What's next ?
  - UFFS2

## Why UFFS ?

- JFFS/JFFS2
  - Can't go out of Linux/MTD
  - Memory monster
- YAFFS/YAFFS2 still consumes too much RAM
  - 64M FLASH, 500 files ==> 410K RAM
- No open source lightweight flash file system exists yet ...

## UFFS design goal

- Ultra low cost
  - Low memory cost
  - Fast booting
- Superb Stability
  - Constant RAM consumption, support static memory allocation
  - Guaranteed integrity across unexpected power losses
  - Bad block tolerant, ECC and ware leveling
- NAND flash friendly
  - Support small (512B) or large page (up to 4KB) size
  - Support SLC and MLC
  - Support software ECC or hardware ECC / RS-ECC
  - Direct flash interface
- Well Emulated on PC platform, easy for debugging

## Flash: NOR vs NAND

- NOR:
  - Random access for read
  - Big block (minimal erase unit)
  - Byte programing
  - Slow erasing/programing
- NAND:
  - Page/spare access for read
  - Small block
  - Page/spare programing (with limited splits/Restricted rewrite)
  - Fast erasing/programing
  - Delivered with bad blocks

## NAND Flash Basic

Page data

Spare

Block

Erase: '0'->'1', Write/Program: '1'->'0'

## What's wrong with FAT

- Need FTL (which may cost many RAM)
- Big FAT table,slow down the whole system
- Vulnerable when unexpectedly interrupted while updating FAT or File info

FAT

File info

Changes

Write File

Changes

File data

Changes

## UFFS basic idea(1)

Parent

Serial

Parent

Serial

Parent

Serial

Parent

Serial

Parent

Serial

Parent

Serial

Parent

Serial

Parent

Serial

Parent

Serial

- Use unique parent/serial number pair to:
  - Identify blocks
  - Build relationships

ROOT

Parent: 16 bit

Serial: 16 bit

## UFFS basic idea(2)

- Build the relationship tree in memory when mounting UFFS:
  - Erased blocks
  - Bad blocks
  - Hash tables (serial number as key)
    - Dir table
    - File table
    - File data table
- Tree node size: 16 bytes
  - Memory cost: 16 * total_blocks

## UFFS basic idea(3)

- Journalizing
  - Write to a new block/page instead of modify the old one.
  - Use circular time stamp: 00->01->11->00>...
  - Check and correct conflicts while mounting UFFS
  - Using “mini-header” eliminates partial page programing requirement

## UFFS Device

- UFFS Device & Mount Point

extern uffs_Device uffs_rootDev;

extern uffs_Device uffs_dataDev;

static struct uffs_mountTableSt femu_MountTbl[] = {

{&uffs_rootDev, 0, 200, "/"},

{&uffs_dataDev, 201, -1, "/data/"},

{NULL, 0, 0, NULL},

};

“/”

“/data/”

UFFS Device ===> Partition
UFFS Device: individual flash ops, cache/buffer, tree nodes ...

## UFFS node tree

- UFFS nodes tree

UFFS device

Bad blocks

Erased blocks

Dir nodes

File nodes

Data nodes

Hash table, serial as the key

block,next

block,next

block,parent,serial,sum,next

block,parent,serial,sum,length(4),next

block,parent,serial,length(2),next

sizeof(TreeNode) = 16B

## UFFS Mounting

- Mounting UFFS

Step 1:

  - Scan page spares*, classify DIR/FILE/DATA nodes
  - Check bad block
  - Check interrupted writing

Step 2:

  - Randomize erased blocks

Step3:

  - Check DATA nodes,take care orphan nodes

Super fast !

* UFFS only read a few spares (normally one or two) from each block rather then all spares !!

UFFS device

Bad blocks

Erased blocks

Dir nodes

File nodes

Data nodes

## UFFS tags

- Page spare/UFFS tags

struct uffs_TagStoreSt {

u32 dirty:1;

u32 valid:1;

u32 type:2;

u32 block_ts:2;

u32 data_len:12;

u32 serial:14;

u32 parent:10;

u32 page_id:6;

u32 reserved:4;

u32 tag_ecc:12;

};

sizeof(struct uffs_TagStoreSt) = 8, small enough to store on spare area

* Note: if using RS-ECC on small page MLC, then tag may store on page data area

## UFFS block info cache

- UFFS block info cache

struct uffs_pageSpareSt {

u8 expired:1;

uffs_Tags tag;

};

struct uffs_blockInfoSt {

struct uffs_blockInfoSt *next;

struct uffs_blockInfoSt *prev;

u16 blockNum;

struct uffs_pageSpareSt *spares;

int expiredCount;

int refCount;

};

uffs_config.h:

MAX_CACHED_BLOCK_INFO(5 ~10)

Memory: 40 bytes for each cached info

## UFFS page buffer

- UFFS page buffer

struct uffs_BufSt{

struct uffs_BufSt *next;

struct uffs_BufSt *prev;

struct uffs_BufSt *nextDirty;

struct uffs_BufSt *prevDirty;

u8 type;

u8 ext_mark;

u16 parent;

u16 serial;

u16 pageID;

u16 mark;

u16 refCount;

u16 dataLen;

u8 * data;

u8 * header;

};

uffs_config.h:

MAX_PAGE_BUFFERS (10 ~ 40)

Memory: (40 + page_size) each buffer

## UFFS page status

Valid page

Discarded page

Free page

- Free page: no page id assigned yet. Free pages are always on the bottom.
- Valid page: the page with a id and have max page offset
- Discarded page: the page with page id, there are one or more pages have the same id and bigger page offset.
- Unknown status: interrupted while writing a page.

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
## UFFS block status

Valid page

Discarded page

Free page

- Bad block
- Free/Erased block
- Non-full loaded block (have one or more free pages)
- Full loaded block (no free page, page id = physical page offset)

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
Bad block

Free block

Non-full loaded block

13

14

15

Full loaded block

## UFFS block recover(1)

- Block recover happens when:
  - No more free pages available inside the block and
  - Data were modified and/or
  - Flush the buffer
- Block recover steps:
  - (1)Get a free/erased block from erased block list
  - (2)Copy pages from old block, write to new block with newer timestamps
  - (3)Erase the old block
  - (4)Put the old block to erased block list
  - Note: (1) and (4) are operating in memory. (2) and (3) identified by timestamps, all steps allow to be interrupted at any time ! (Guaranteed integrity across unexpected power losses)

## UFFS block recover(2)

- No block recover if there are enough free pages

Block 1234

0

Block 1234

0

1

1

Since there are free pages, no block recover happens.

Mark old page as discarded, and generate a new page.

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
Valid page

Discarded page

Free page

## UFFS block recover(3)

- Recover a non-full loaded block

Block 1234

0

Block 5678

0

1

No more free page available in this block, modify any pages from 0-7, or add a new page 8, will cause block recovering.

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
Valid page

Discarded page

Free page

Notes: See uffs_buf.c: static URET _BufFlush_Exist_With_BlockCover ( uffs_Device *dev, TreeNode *node, uffs_blockInfo *bc )

## UFFS block recover(4)

- Recover a full-loaded block

Block 1234

0

Block 5678

0

Modify any page of full-loaded block will cause block recovering.

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
Valid page

Discarded page

Free page

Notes: See uffs_buf.c: static URET _BufFlush_Exist_With_BlockCover ( uffs_Device *dev, TreeNode *node, uffs_blockInfo *bc )

## UFFS Page layout

Status byte

mini-

header

Seal byte

ECC

DATA

Tag

- Mini-header (4B) and DATA on page data area, Tag, ECC and 'seal byte' on spare area
- In some case (for example, when using hardware RS-ECC on small page MLC), you can treat the whole NAND page as one body, blur the page data and spare area boundary.
- The 'status byte': this is the first byte of mini-header. If status byte is not 0xFF – this page is “dirty”, page program already started.
- The 'seal byte': this is the last byte of spare data. If seal byte is not 0xFF – this page is “sealed”, all data and tag/ECC have been programmed successfully.

## UFFS bad block management

- Bad block discover when mounting UFFS
- Bad block discover when read/write/erase
  - Try ECC error correct
  - If ECC fail, there is no way get valid data
  - Do not process bad block immediately, leave it at the end of Read/Write operation.
  - Only handle one bad block during the one read/write operation.
- Check bad block when formating UFFS

## How ECC works ? (1)

- XOR: A ^ B = C
  - 0 ^ 0 = 0
  - 1 ^ 0 = 1
  - 0 ^ 1 = 1
  - 1 ^ 1 = 0
- Knowing any two of A, B and C, will know the rest one.
- UFFS ECC: 3 bytes ECC for 256 bytes data
  - 256 Bytes ==> 2048 Bits ===> 256(row) X 8(col)

## How ECC works ? (2)

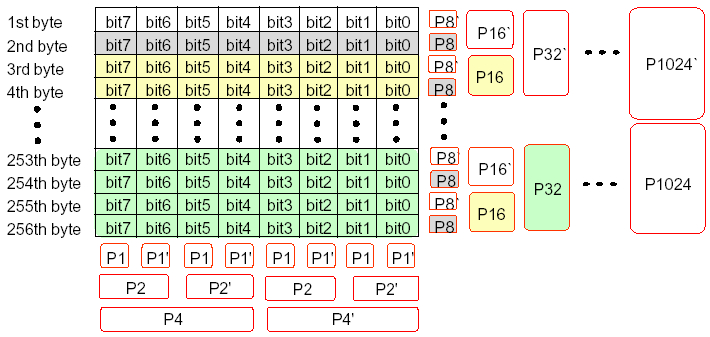
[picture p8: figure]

## UFFS Flash Interface

- struct uffs_FlashOpsSt:
  - Use hardware ECC, or leave it to UFFS
  - Allow driver do the spare layout, or leave it to UFFS
  - Return flash operation status
  - Sequential page programing. No partial page programing.

## UFFS Limitations

- Only one file/dir on one block
- Dynamic wear-leveling, Static wear-leveling is not implemented.

## The next: UFFS2 ?

- Smaller Tree Node (12 bytes), save 25% RAM
- Use NAND block as buffers
- Multiple files/dirs on one block
- Support 8K, 16K page size
- Static wear-leveling
- Symbol link, FIFO file ?
- NOR flash support ? Maybe ...

## The End

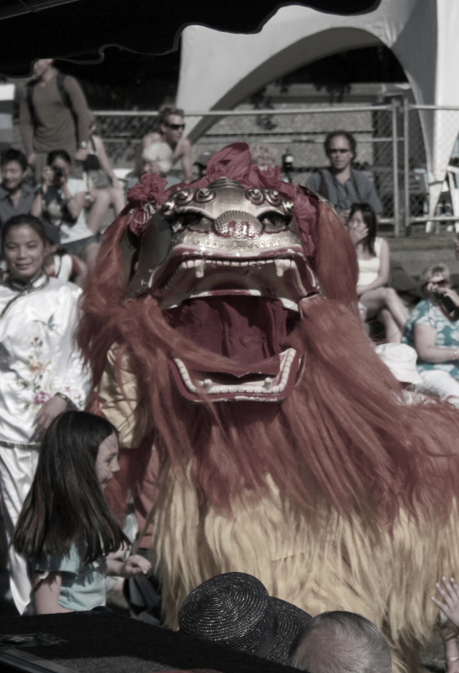
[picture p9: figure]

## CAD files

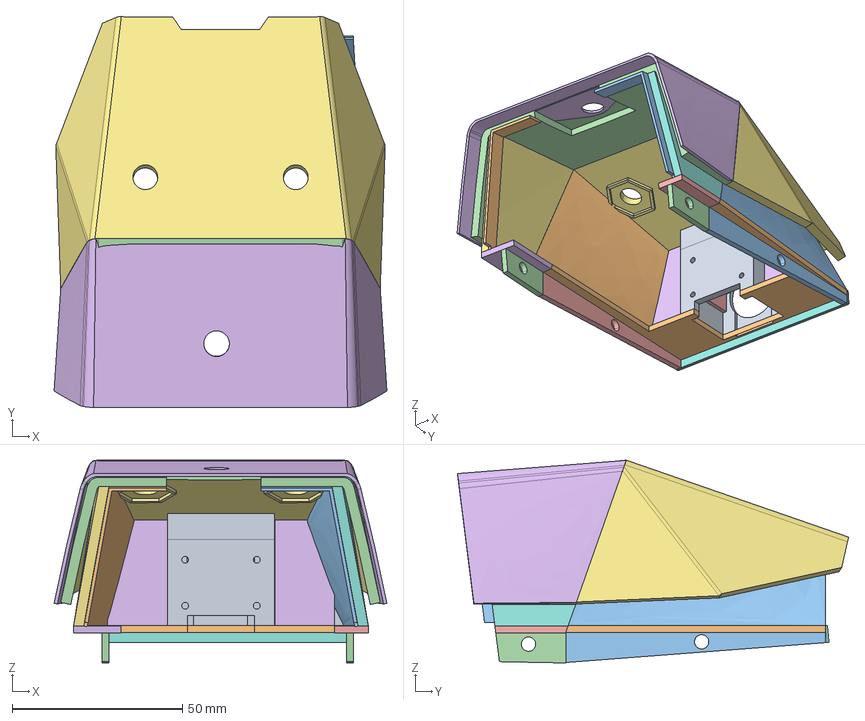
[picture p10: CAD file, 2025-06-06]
3DPrint/body.stp
97.6 x 114.7 x 59.5 mm

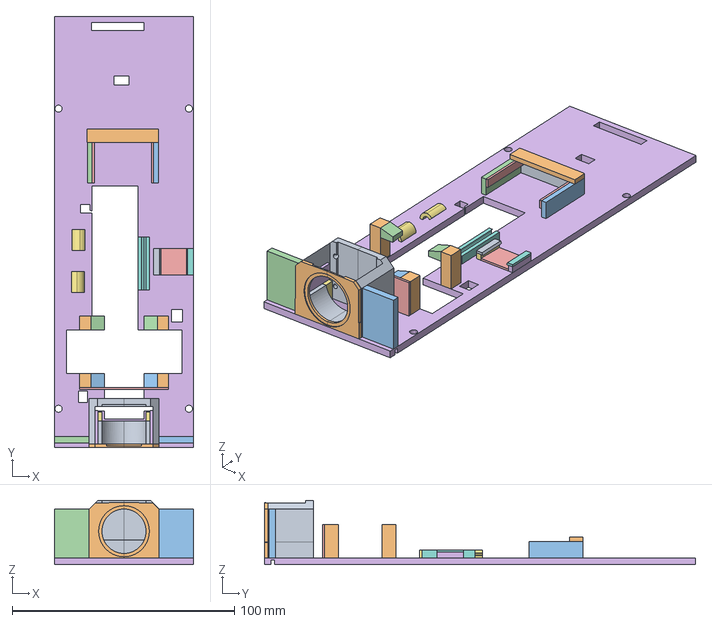
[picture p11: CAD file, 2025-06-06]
3DPrint/mini_cover.stp
62.6 x 194.0 x 28.8 mm

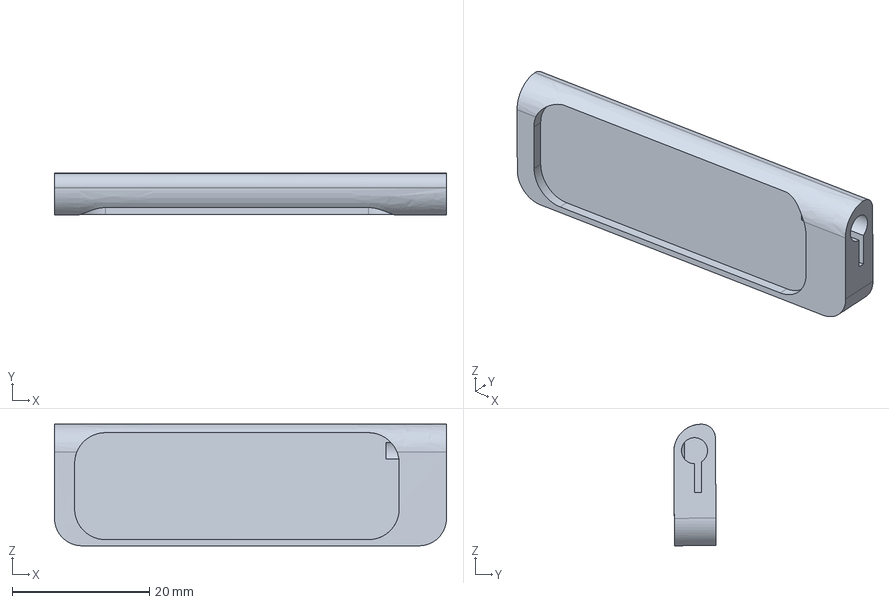
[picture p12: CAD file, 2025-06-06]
3DPrint/back_cover.stp
57.1 x 6.18 x 17.7 mm

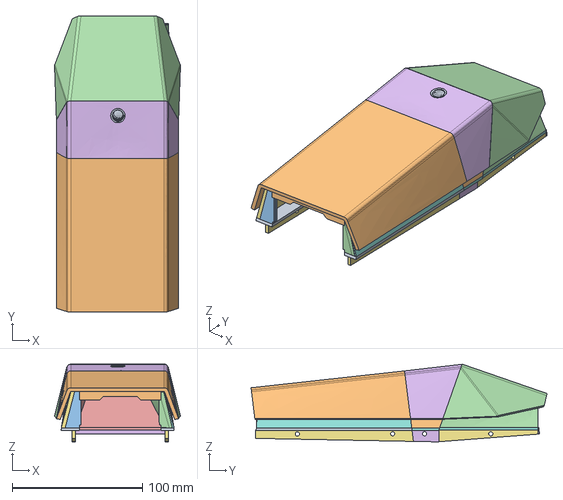
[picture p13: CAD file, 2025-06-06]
3DPrint/front_top.stp
96.6 x 226.9 x 59.7 mm

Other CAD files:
3DPrint/v6-mini+.stp

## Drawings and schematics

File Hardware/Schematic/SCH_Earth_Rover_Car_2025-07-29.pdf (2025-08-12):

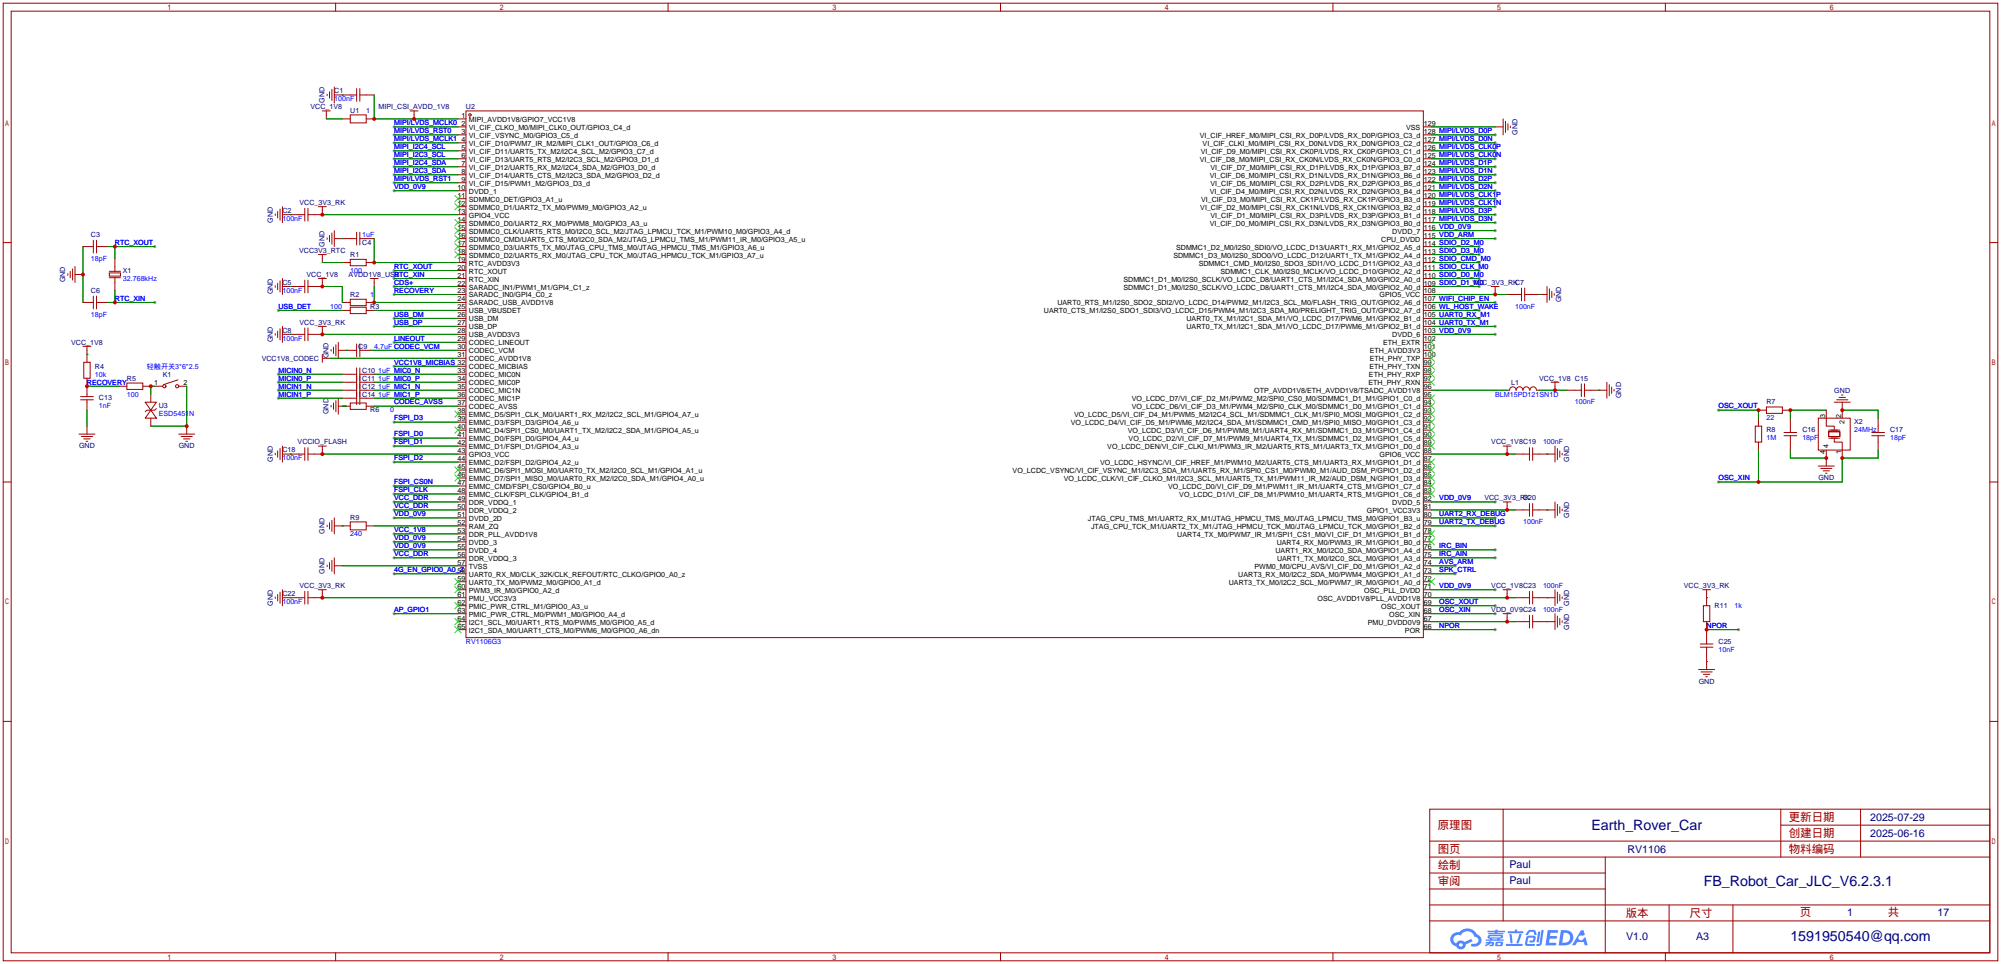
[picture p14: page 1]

# 12V --> VCC5V0_SYS

# VCC5V0_SYS --> VCC_1V8(Step 2)

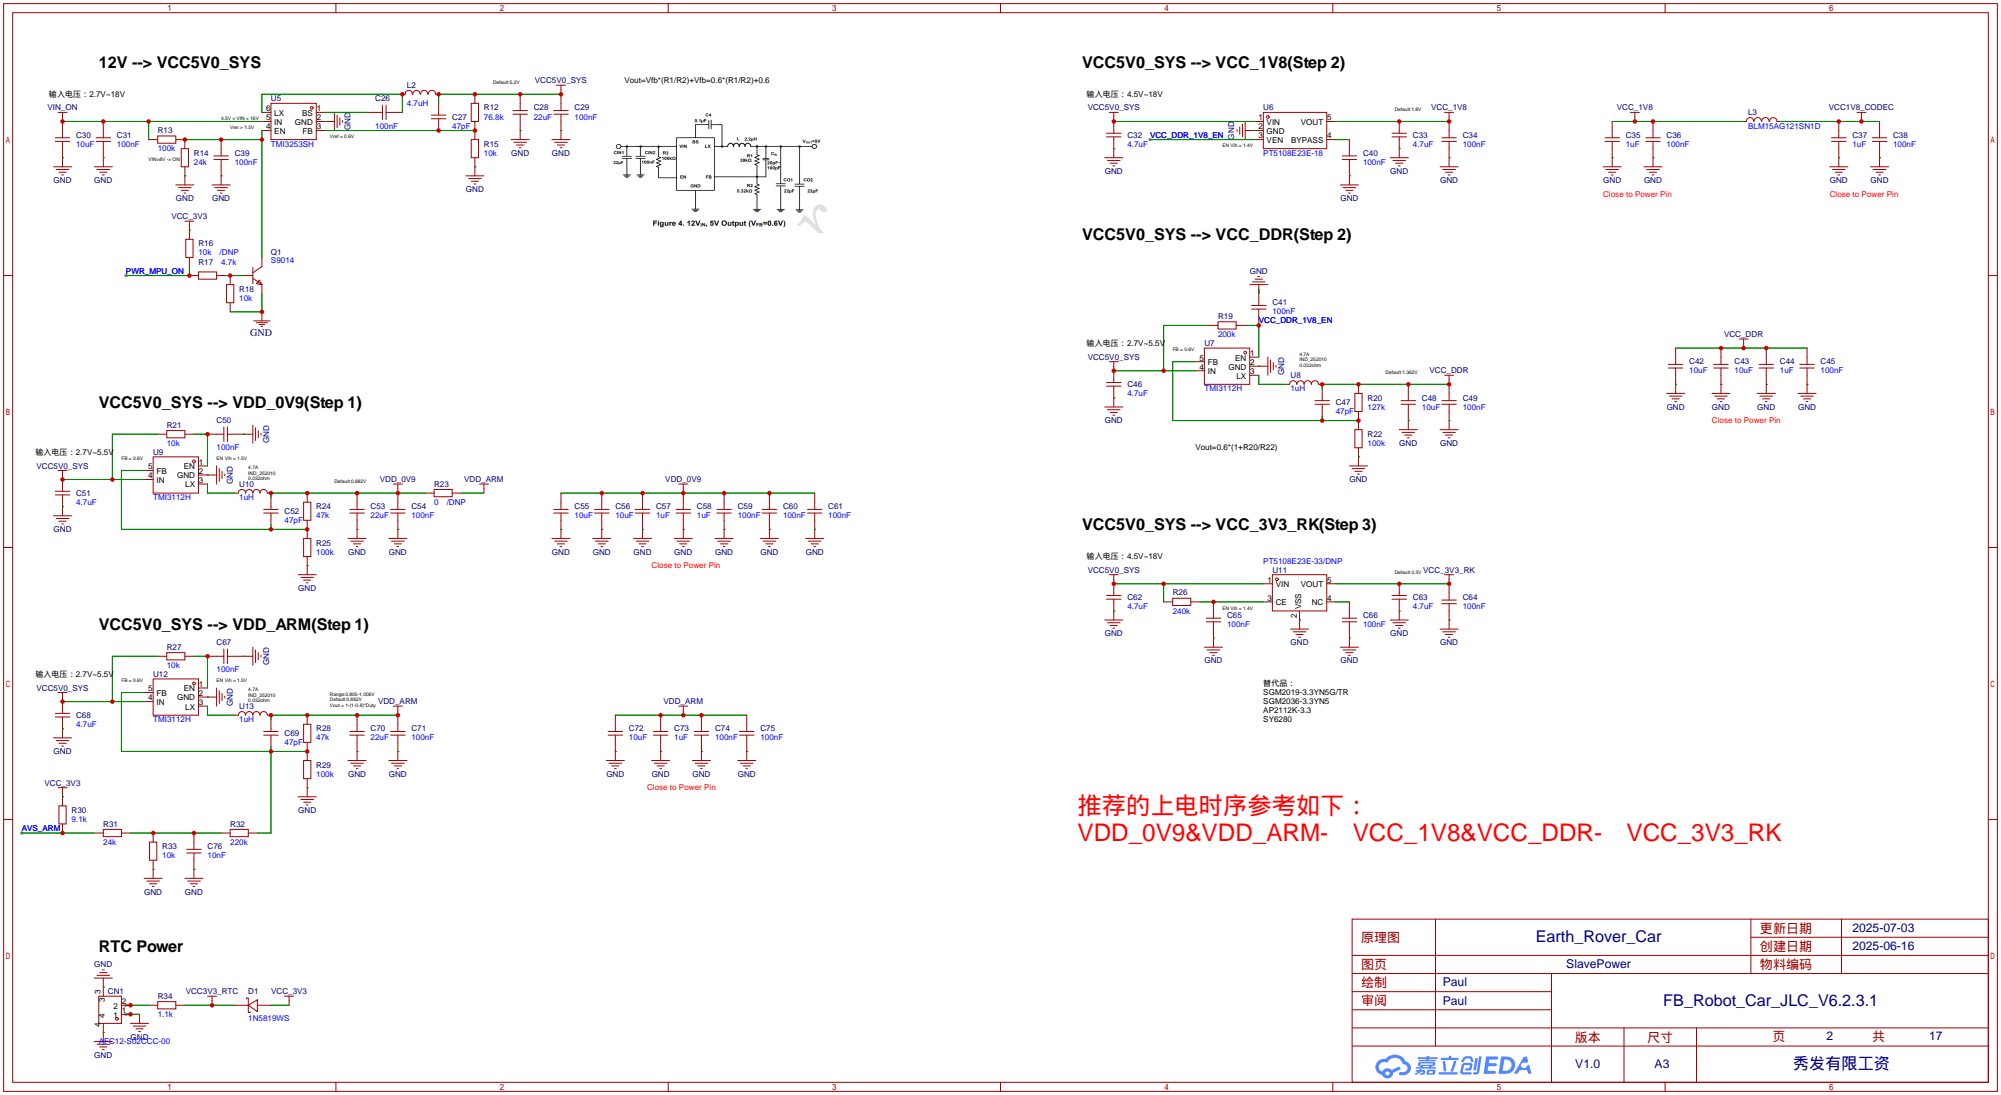
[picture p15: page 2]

Close to Power Pin

GND

MIC | Speaker Out

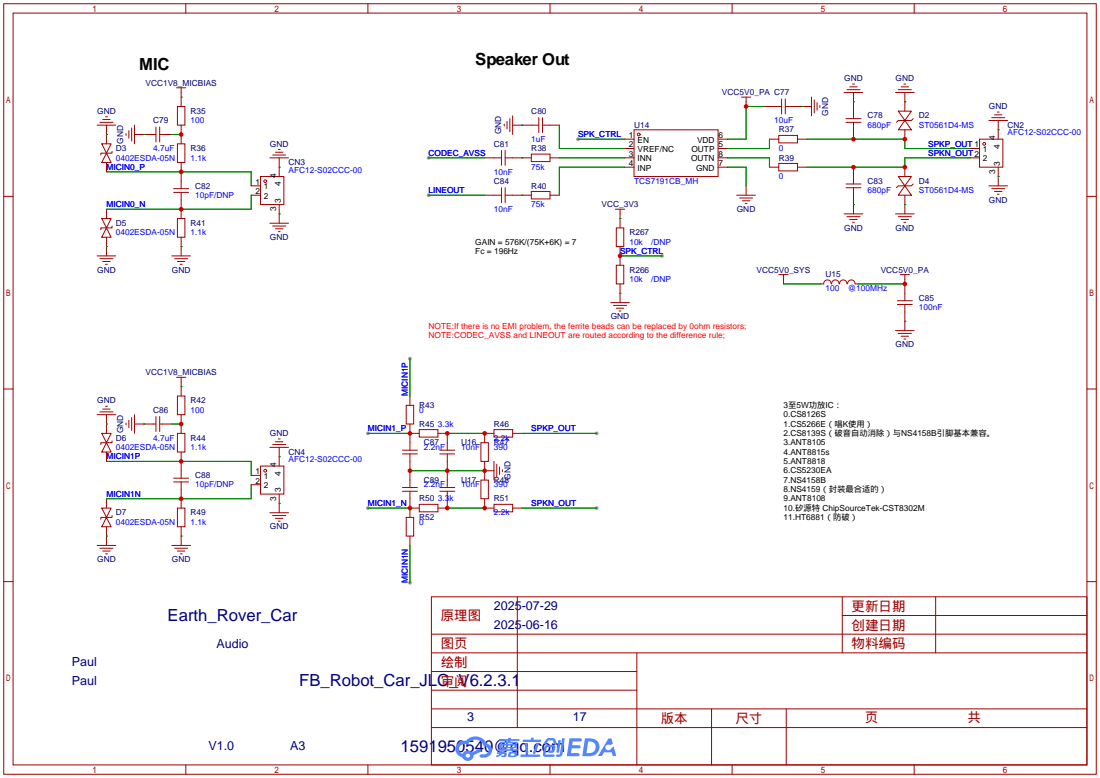
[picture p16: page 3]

NOTE:If there is no EMI problem, the ferrite beads can be replaced by 0ohm resistors;
NOTE:CODEC_AVSS and LINEOUT are routed according to the difference rule;

# WIFI

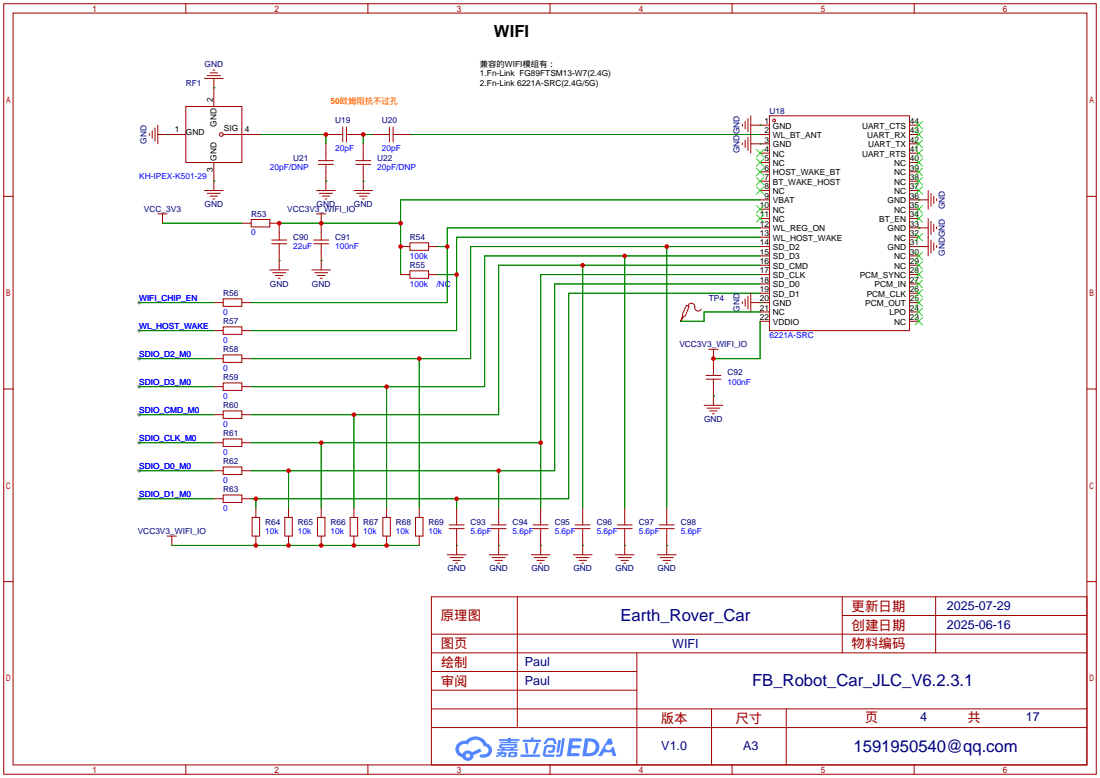
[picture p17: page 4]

# USB Type C

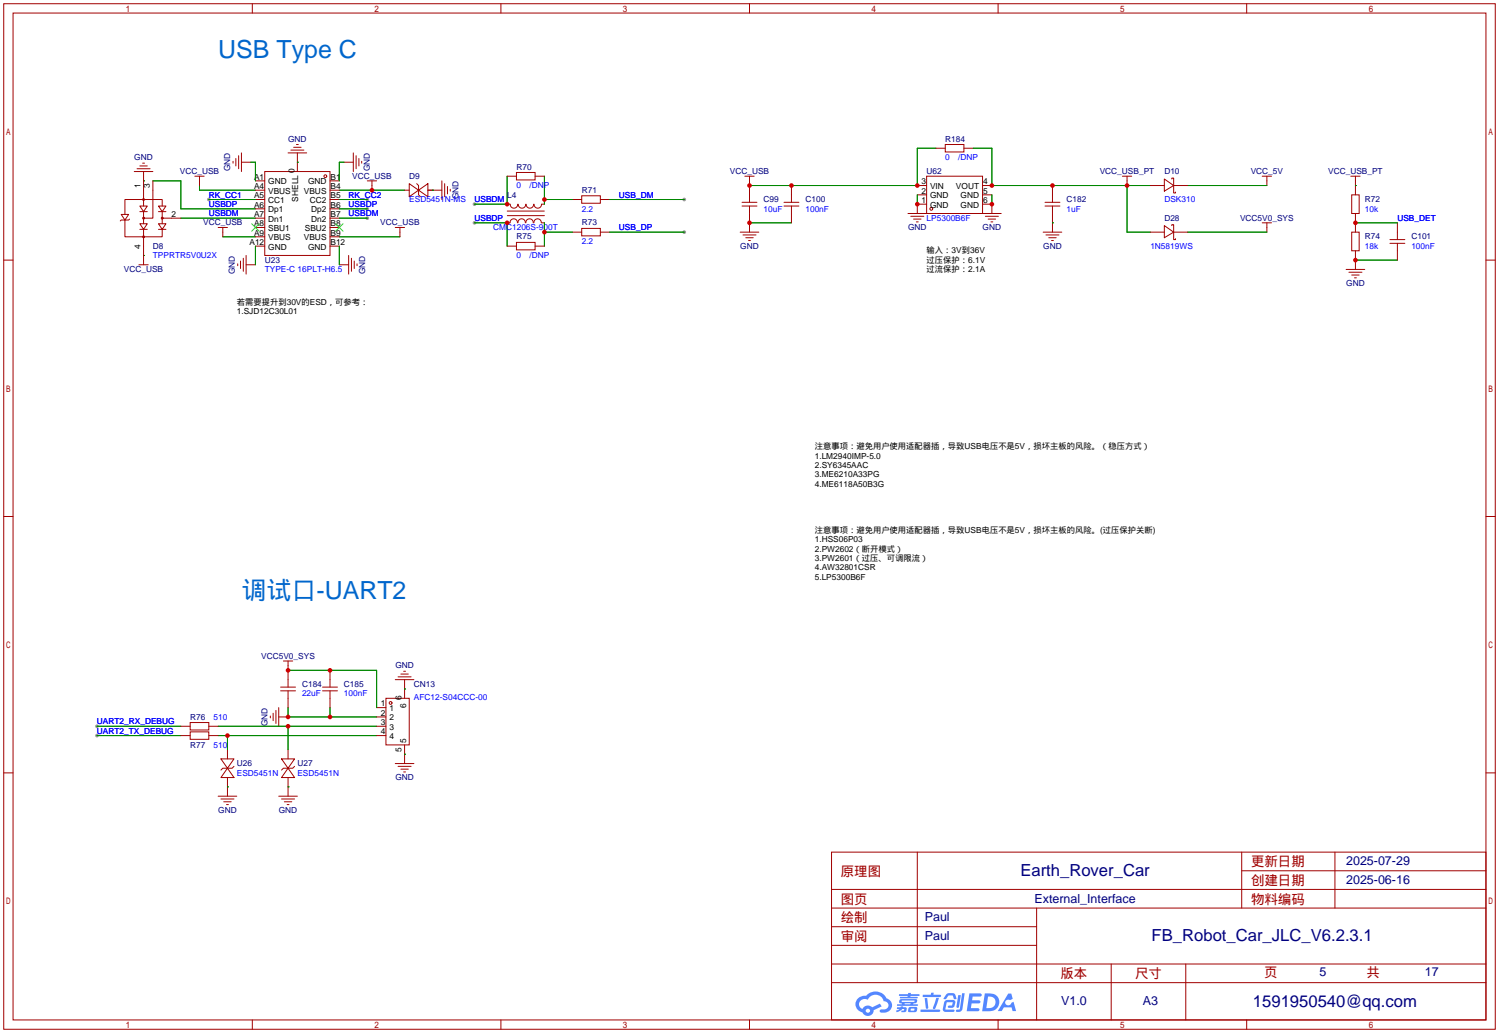
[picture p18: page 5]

# PCIE 4G

# PCIE-4G模组

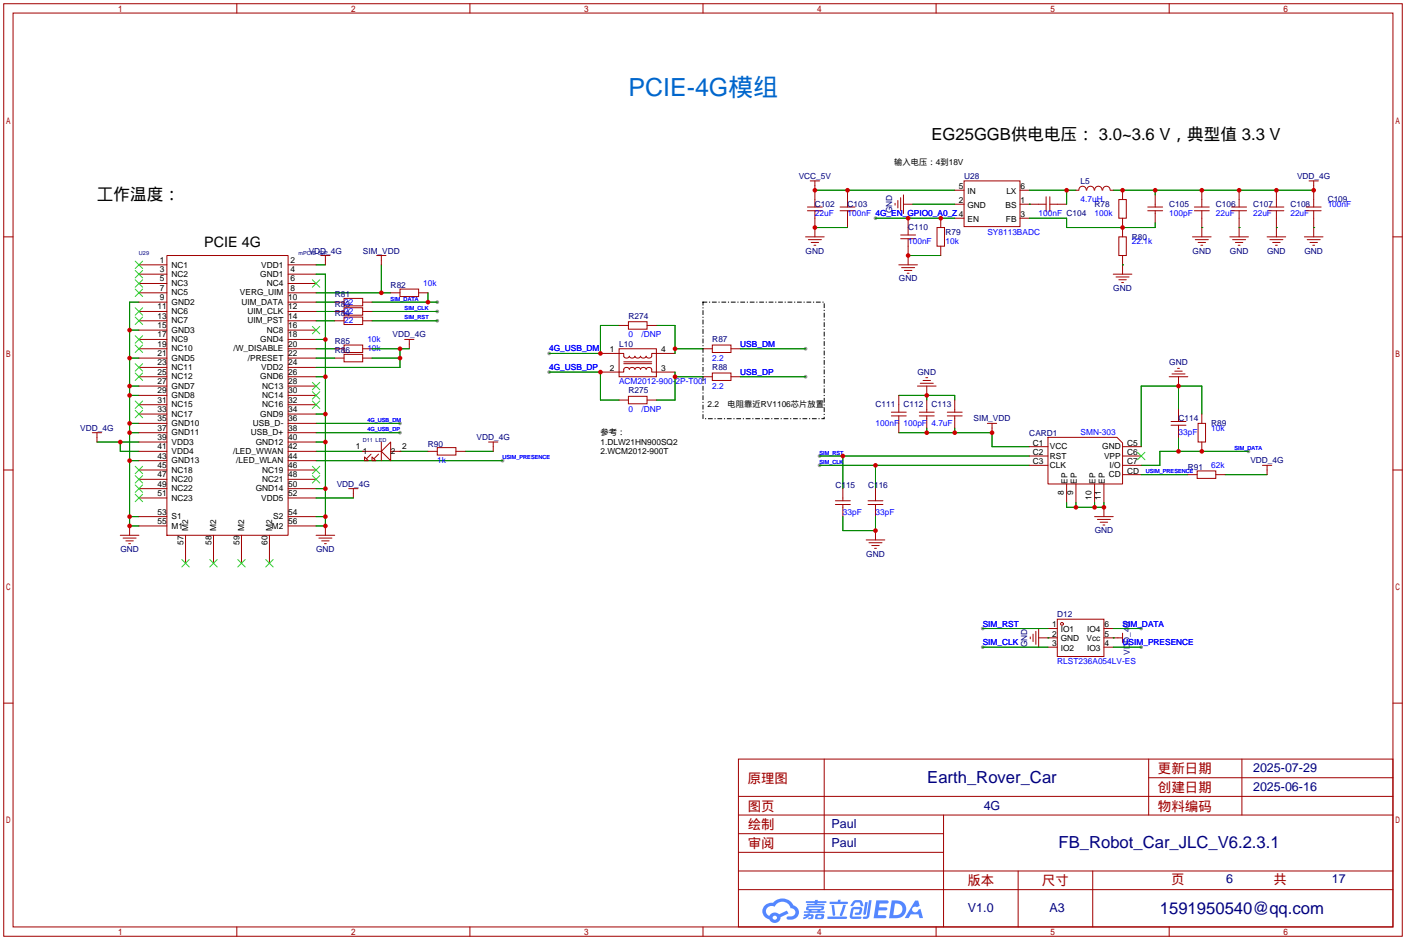
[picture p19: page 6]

IR-CUT Drive | CDS&LED

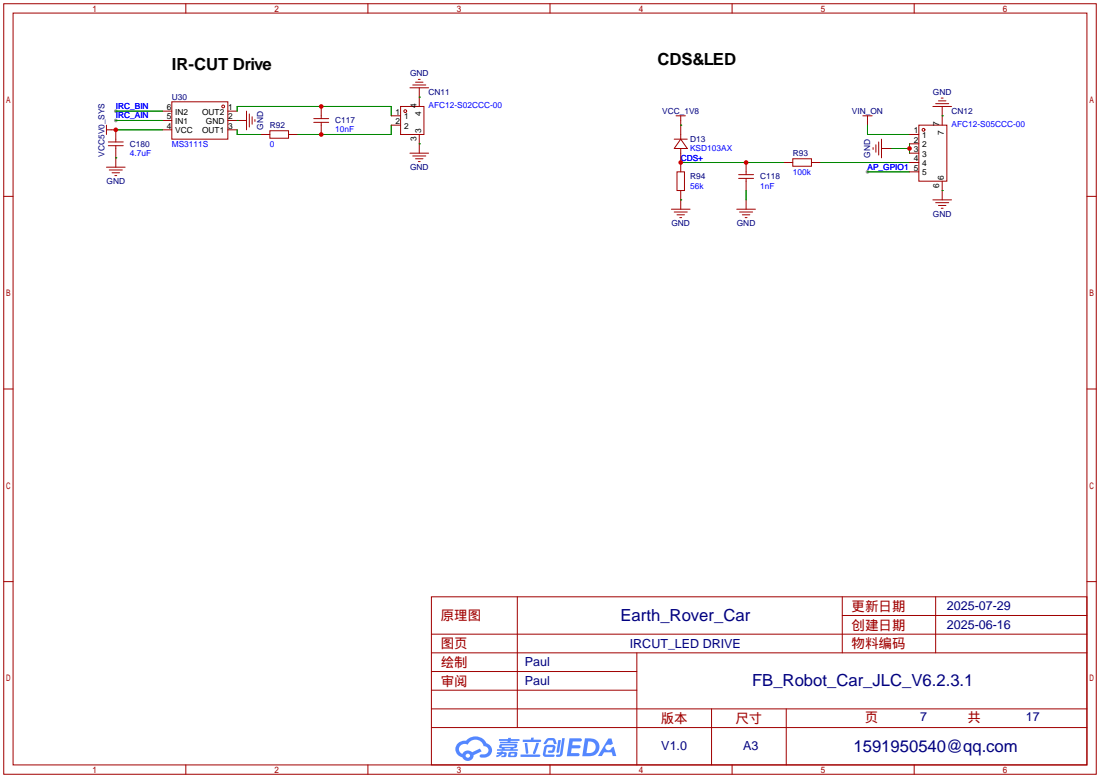
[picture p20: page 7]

# FSPI_CLKFSPI_D³

# SPI NAND FLASH 1G

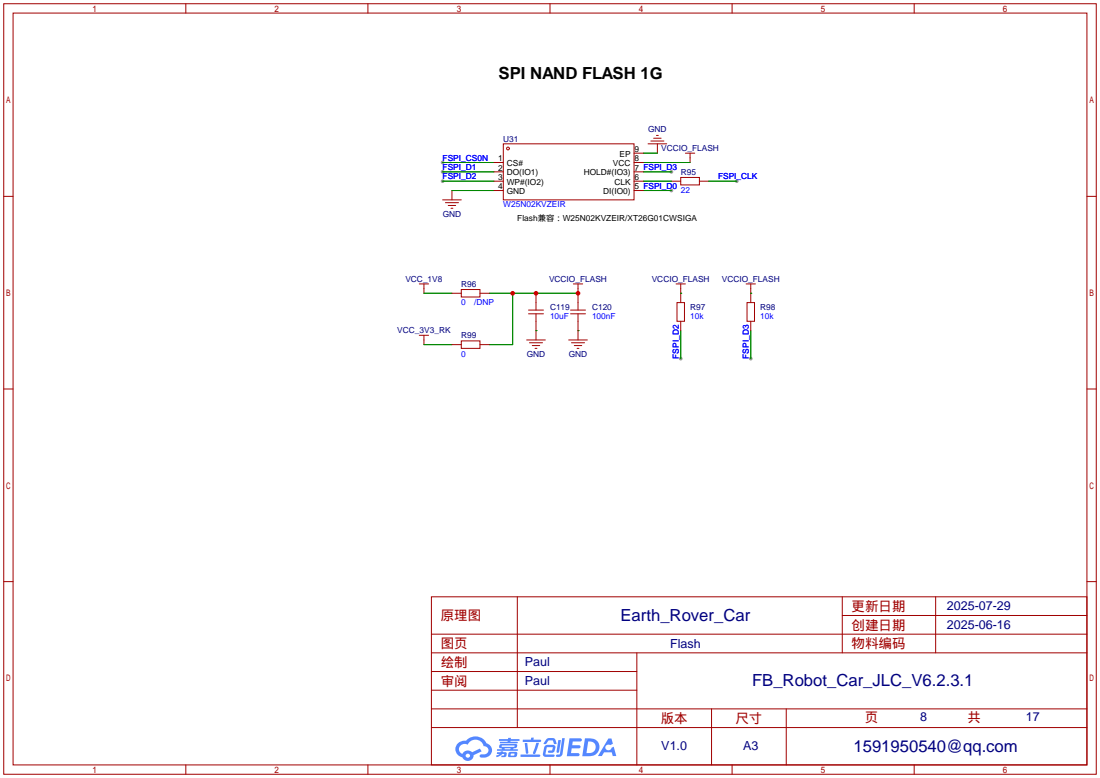
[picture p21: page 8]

# MIPI CSI 2LANE*2

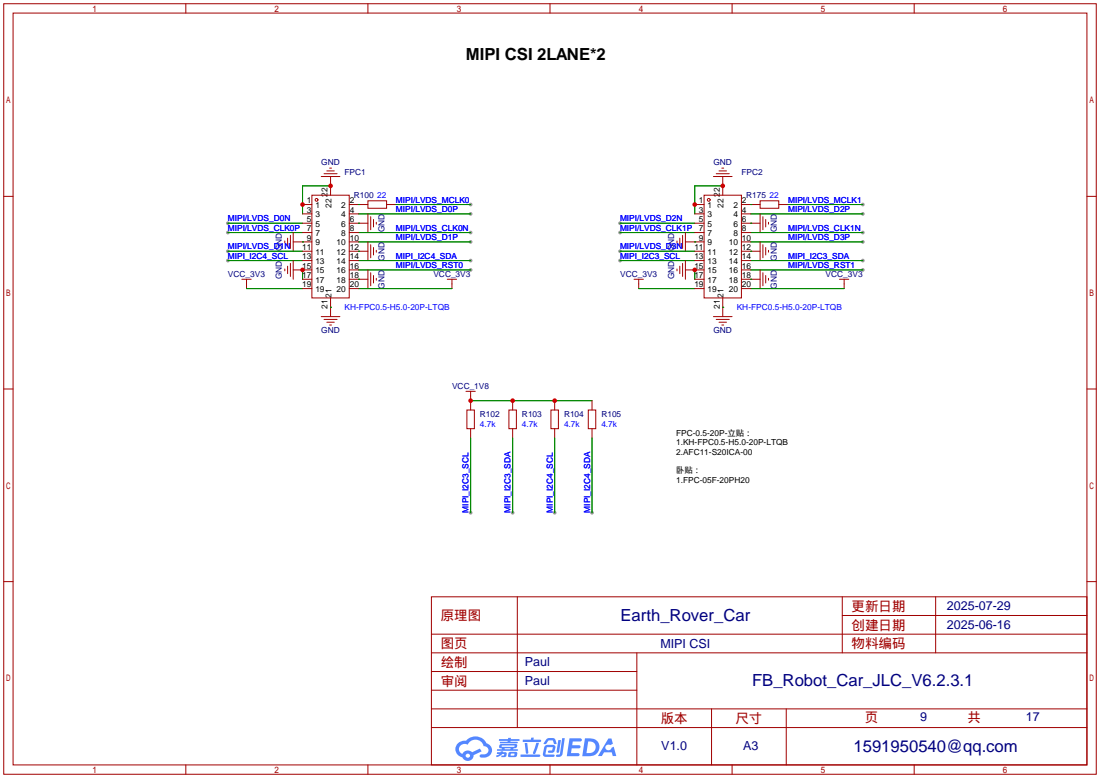
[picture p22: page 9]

# OTA复位时系统不掉电/电源指示灯VCC_3V³

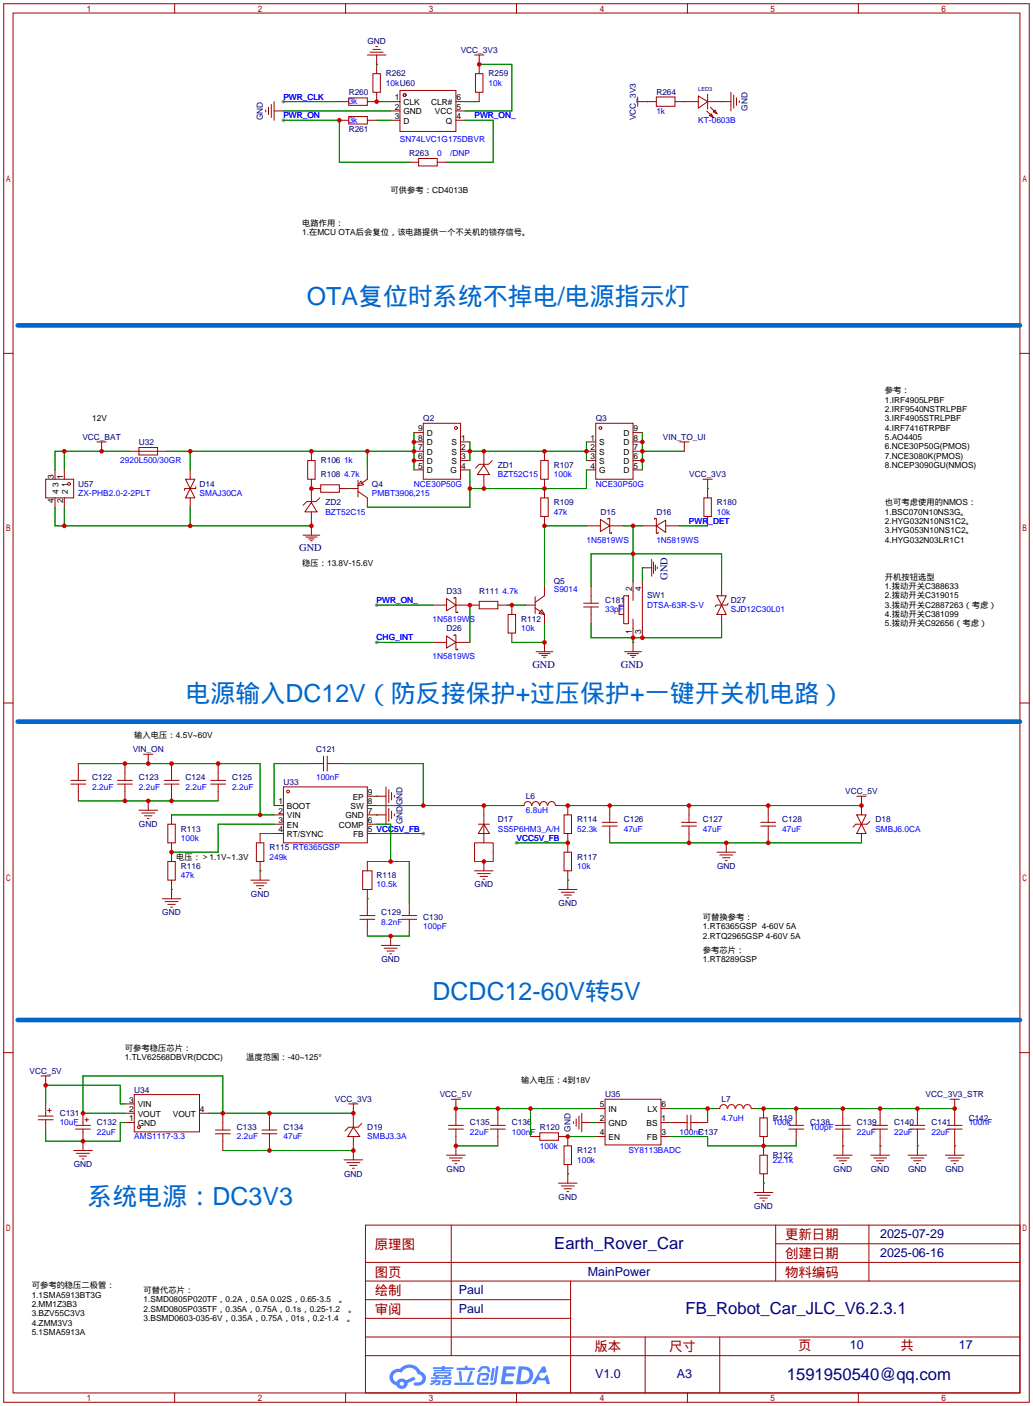
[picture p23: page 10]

# SW3516/HUB839

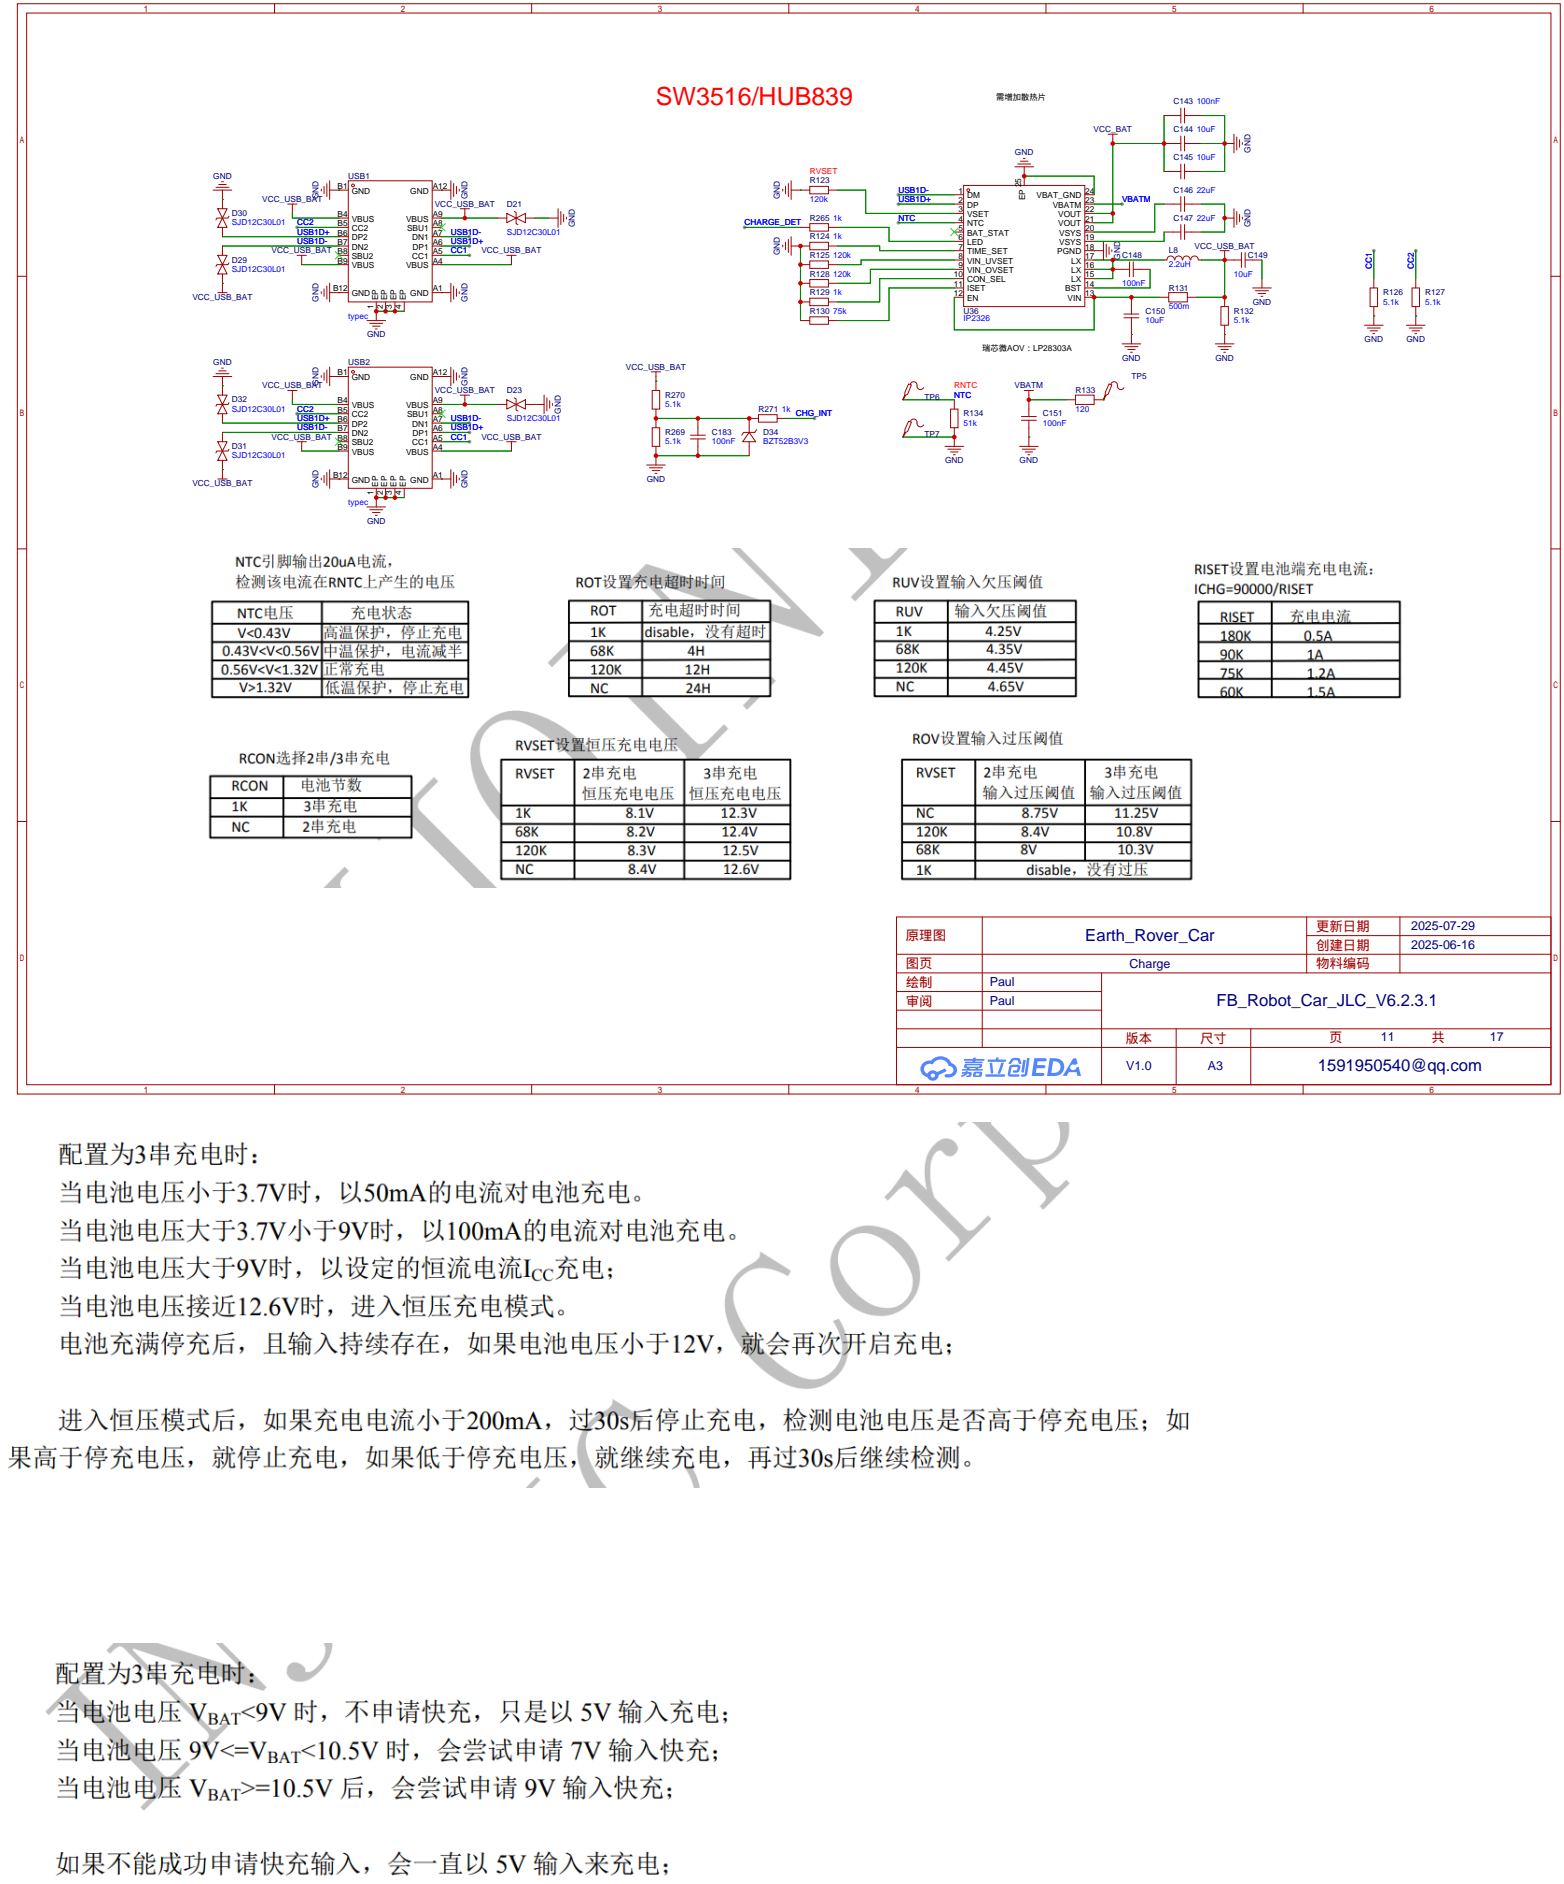
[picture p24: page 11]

# 2路直流无刷电机驱动接口

# 2路电机电流采集

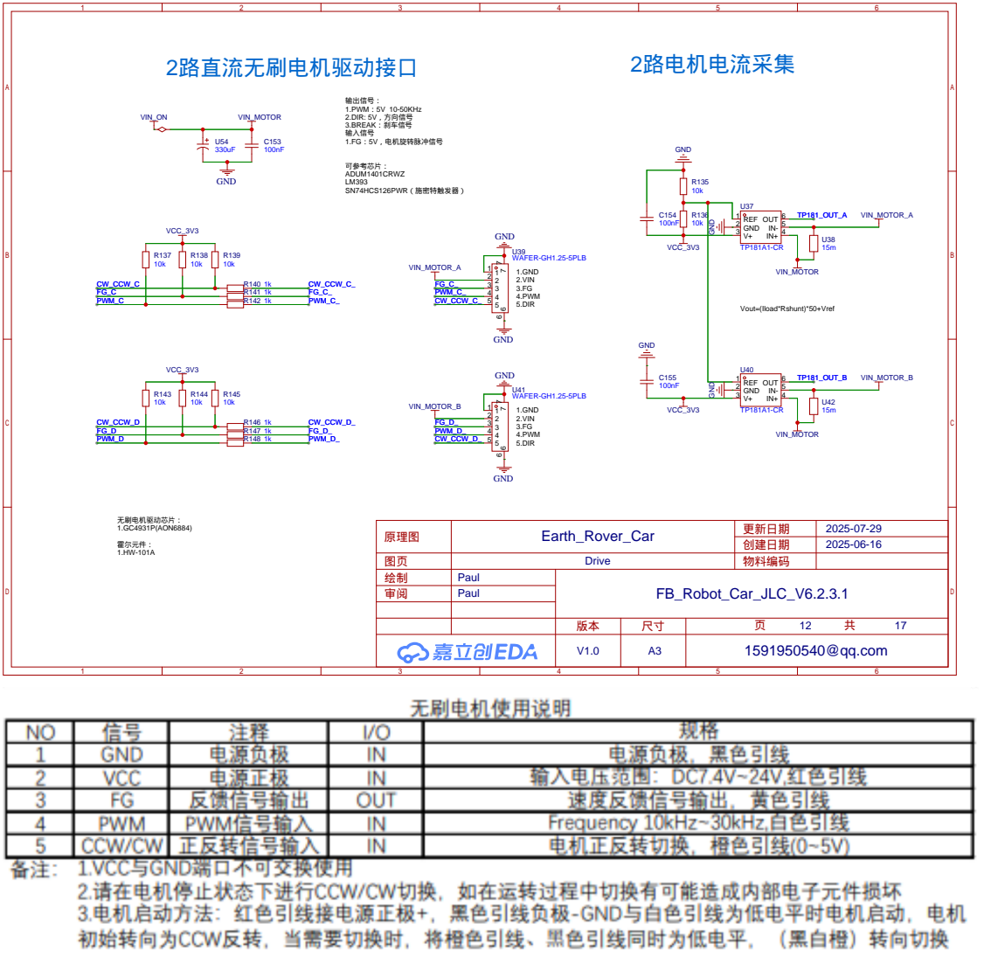
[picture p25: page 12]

Vout=(Iload*Rshunt)*50+Vref

# C1 10 GND 11 NC 12 NC 13 NC 14 NC 15 SDA 16


# 备份电源

# 复位电路


名称 | 数量 | 规格 | 选配 | IO分配

电源指示灯 | 1路 | 三色灯

开关机按钮 | 1路 | | 必要

充电检测 | 1路 | | 必要

电压检测 | 1路 | 1路总电压12.6V | 必要

电流检测 | 3路 | 1路总电流、2路电机电流 | 可选
IMU | 1路 | 9轴 | 必要

电机 | 2路 | 无刷电机 | 必要
RPM | 2路 | | 必要

电池管理 | 1路 | 3串锂电池充电 | 必要


# 电量指示灯

# 状态指示灯


# 对外拓展口


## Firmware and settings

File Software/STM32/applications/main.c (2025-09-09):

/*
 * Copyright (c) 2006-2024, RT-Thread Development Team
 *
 * SPDX-License-Identifier: Apache-2.0
 *
 * Change Logs:
 * Date           Author       Notes
 * 2024-02-29     RT-Thread    first version
 */
#include "main.h"
#include "fal.h"

#define DBG_TAG "main"
#define DBG_LVL DBG_LOG
#include <rtdbg.h>
#include "pwm_ic.h"
#include "QMC5883L.h"
#include "./WS2812/ws2812b.h"

static rt_thread_t uart_tid = RT_NULL;
static rt_thread_t uart_tim_tid = RT_NULL;
static rt_thread_t motor_tid = RT_NULL;
static rt_thread_t state_tid = RT_NULL;
//static rt_thread_t sensor_tid = RT_NULL;
static rt_thread_t protect_tid = RT_NULL;
static rt_thread_t imu_tid = RT_NULL;
static rt_thread_t pid_uart_tid = RT_NULL;
static rt_thread_t motor_test_tid = RT_NULL;

// Externally defined functions for thread startup
extern void uart_thread_entry ( void *parameter );
extern void uart_send_thread_entry ( void *parameter );
extern void serial_thread_entry(void *parameter);
extern void motor_thread_entry ( void *parameter );
extern void state_thread_entry ( void *parameter );
extern void sensor_thread_entry ( void *parameter );
extern void protect_overload_thread_entry ( void *parameter );
extern void imu_thread_entry ( void *parameter );
extern void pid_uart_thread_entry ( void *parameter );
extern void motor_test_thread_entry ( void *parameter );
extern void set_pwr_rgbled_color ( rt_bool_t red , rt_bool_t green , rt_bool_t blue );

extern void set_sys_rgb_led_color_flash (rt_uint16_t on_time, system_state_t sys_status);
extern void LED_system_init(rt_uint16_t on_time,float black_coeff);
extern void robot_lamp_on ( void );
extern void robot_lamp_off ( void );

extern int wdt_init ( void );
extern int hwtimer_init ( void );
extern void motor_init_pwm ( void );
extern void strategy_init ( void );
extern void led_pwr_status_init ( void );

extern void robot_power_on ( void );
extern void robot_power_off ( void );
extern void robot_power_out_on ( void );
extern void robot_power_out_off ( void );
RTC_HandleTypeDef hrtc; //local instnace of RTC

extern void rt_memory_info(rt_uint32_t *total, rt_uint32_t *used, rt_uint32_t *max_used);

void check_heap_size(void)
{
    rt_uint32_t total, used, max_used;
    rt_memory_info(&total, &used, &max_used);

    rt_kprintf("Heap Total: %d bytes\n", total);
    rt_kprintf("Heap Used: %d bytes\n", used);
    rt_kprintf("Heap Max Used: %d bytes\n", max_used);
}
MSH_CMD_EXPORT(check_heap_size, check RT-Thread heap size);

int main ( void )
{
	  fal_init ( ); // initialized all flash devices and partitions
//	  strategy_init ( );

	// defines thread for Universal Asynchronous Receive-Transmission protocol
	// Function: rt_thread_create
	// Input: 
	// 		- Thread name
	// 		- Thread Entry Function
	//		- Extra Parameters (unsure what these parameters are for)
	//		- Stack size needed
	// 		- Priority Level
	// 		- Tick (unsure what tick is)
	// Output: rt_thread struct. Struct has name, type, flags, and MANY more parameters.
	  uart_tid = rt_thread_create ( "uart" , uart_thread_entry , RT_NULL , 24 * 1024 , 20 , 15 ); // stack size = 24*1024, priority = 20, tick = 15

	  if ( uart_tid != RT_NULL )
	  {
	      rt_thread_startup ( uart_tid ); // put thread obj to general thread startup function
	  }

	  uart_tim_tid = rt_thread_create ( "uart_tim_send" , uart_send_thread_entry , RT_NULL , 12 * 1024 , 20 , 15 );

	  if ( uart_tim_tid != RT_NULL )
	  {
	      rt_thread_startup ( uart_tim_tid );
	  }

	  motor_tid = rt_thread_create ( "motor" , motor_thread_entry , RT_NULL , 4 * 1024 , 15 , 25 );
	  if ( motor_tid != RT_NULL )
	  {
			rt_thread_startup ( motor_tid );
	  }

	  state_tid = rt_thread_create ( "state" , state_thread_entry , RT_NULL , 12 * 1024 , 25 , 11 );
	  if ( state_tid != RT_NULL )
	  {
			rt_thread_startup ( state_tid );
	  }

	  imu_tid = rt_thread_create ( "imu" , imu_thread_entry , RT_NULL , 12 * 1024 , 24 , 25 );
	  if ( imu_tid != RT_NULL )
	  {
	      rt_thread_startup ( imu_tid );
	  }

//	  motor_test_tid = rt_thread_create ( "motor_test" , motor_test_thread_entry , RT_NULL , 4 * 1024 , 24 , 26 );
//	  if ( motor_test_tid != RT_NULL )
//	  {
//	      rt_thread_startup ( motor_test_tid );
//	  }

//	  pid_uart_tid = rt_thread_create ( "pid_uart" , pid_uart_thread_entry , RT_NULL , 16 * 1024 , 30 , 10 );
//	  if ( pid_uart_tid != RT_NULL )
//	  {
//	      rt_thread_startup ( pid_uart_tid );
//	  }

//	  sensor_tid = rt_thread_create ( "state" , sensor_thread_entry , RT_NULL , 4096 , 25 , 10 );
//	  if ( sensor_tid != RT_NULL )
//	  {
//			rt_thread_startup ( sensor_tid );
//	  }

//	  protect_tid = rt_thread_create ( "protect" , protect_overload_thread_entry , RT_NULL , 4096 , 25 , 10 );
//	  if ( protect_tid != RT_NULL )
//	  {
//			rt_thread_startup ( protect_tid );
//	  }
	  wdt_init ( );
	  hwtimer_init ( ); // assuming this inits the hwtimer.c functionality

	  /**WS2812 Init**/
	  ws2812_init(); // Initializes WS2812 driver
	  ws2812_clearn_all(2);
	  
	  robot_power_init ();//开关机初始化 = Power on/off initialization
	  robot_charge_init();//充电检测初始化 = Charging detection initialization
	  
	  // 检测 OTA 状态 = Check OTA status
	  hrtc.Instance = RTC;
	  HAL_RTC_Init(&hrtc);
	  uint32_t ota_reboot=HAL_RTCEx_BKUPRead(&hrtc, RTC_BKP_DR0);
//	  rt_kprintf("ota_flag = 0x%X\n",ota_flag);
	  if (ota_reboot == 0xA5A5) {
	      // OTA 后首次重启逻辑 = First reboot after OTA logic
	      robot_state.pwr = 1;
	      robot_state.status = SYSTEM_STATE_RUNNING;
	      robot_state.net_led_status = UCP_NETWORK_CONNECTED;
	      robot_power_on ( );
	      robot_power_out_on ( );

	      // 清除标志，防止下次复位依然触发 = Clear the flag to prevent triggering again on next reset
	      HAL_RTCEx_BKUPWrite(&hrtc, RTC_BKP_DR0, 0x0000);
	  } else {
	      // 普通启动逻辑 = Normal startup logic
	      robot_state.status = SYSTEM_STATE_INITIAL;
	  }

	  while ( 1 )
	  {
		  // 充电状态检测任务(优先判定) = Charging status detection task (priority determination)
	      robot_charge_task();

	      switch (robot_state.status) {
              case SYSTEM_STATE_CHARGING:
			  		// Function: set_sys_rgb_led_color_flash
					// Input: 
					// 		- rt_uint16_t (int) on_time
					// 		- system_state_t (int) sys_status = code associated with robot state.
					// Output: NULL

					// Function: LED_system_init
					// Input: 
					// 		- 
					// Output: NULL

					// Function: rt_thread_mdelay
					// Input: 
					// 		- 
					// Output: NULL
					
				  set_sys_rgb_led_color_flash(1000,0);// 充电中，更新电源指示灯为慢闪烁状态 = Charging, update power indicator to slow flashing
				  break;
              case SYSTEM_STATE_CHARGED:
				  set_sys_rgb_led_color_flash(1000,1);// 充电完毕，更新电源指示灯为常亮状态 = Charging complete, update power indicator to steady on
				  break;
	          case SYSTEM_STATE_INITIAL:
				  LED_system_init(100,0.5);// 初始状态(开机提示) = Initial state (power-on prompt)
	              break;
	          case SYSTEM_STATE_RUNNING:
				  set_sys_rgb_led_color_flash(1000,3);// 系统开机运行中，执行正常任务 = System running, performing normal tasks
	              break;
	          case SYSTEM_STATE_WARNING:
				  set_sys_rgb_led_color_flash(300,0);// 系统电量不足10%，红灯快闪烁警告 = System power less than 10%, red light fast flashing warning
	              break;
	          case SYSTEM_STATE_SHUTDOWN:
				  rt_thread_mdelay ( 800 );// 系统关机或停止运行，进入低功耗状态 = System shutdown or stopped, enter low power state
	              break;
	          default:
	              break;
	      }
		  // main function - boot up main threads for taking care of individual parts of robot, once done, and robot_state is setup: only look at power state and take care of LED signals for power.

//			clock_information();
//			rt_kprintf("System Clock information\n");
//			rt_kprintf("SYSCLK_Frequency = %d\n", HAL_RCC_GetSysClockFreq());
//			rt_kprintf("HCLK_Frequency   = %d\n", HAL_RCC_GetHCLKFreq());
//			rt_kprintf("PCLK1_Frequency  = %d\n", HAL_RCC_GetPCLK1Freq());
//			rt_kprintf("PCLK2_Frequency  = %d\n", HAL_RCC_GetPCLK2Freq());
//			LOG_I( "LED_PWR_G = %d" ,rt_pin_read(LED_PWR_G));
//			rt_thread_mdelay ( 100 );
//			rt_pin_write ( LED_PWR_G , 1 );
//			LOG_I( "LED_PWR_G = %d" ,rt_pin_read(LED_PWR_G));
//			LOG_I( "OTA successful! \n");

	  }
	  return RT_EOK;
}

#if 1
static int ota_app_vtor_reconfig ( void )
{
#define NVIC_VTOR_MASK 0x3FFFFF80
#define RT_APP_PART_ADDR 0x08020000
	  SCB->VTOR = RT_APP_PART_ADDR & NVIC_VTOR_MASK;

	  return 0;
}
INIT_BOARD_EXPORT( ota_app_vtor_reconfig );
#endif

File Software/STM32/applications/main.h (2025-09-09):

/*
 * Copyright (c) 2006-2021, RT-Thread Development Team
 *
 * SPDX-License-Identifier: Apache-2.0
 *
 * Change Logs:
 * Date           Author       Notes
 * 2024-04-14     luozs       the first version
 */
#ifndef APPLICATIONS_MAIN_H_
#define APPLICATIONS_MAIN_H_

#include <rtthread.h>
#include <rtdevice.h>
#include <drv_common.h>
#include <stdint.h>
#include <stdlib.h>
#include <math.h>
#include "state.h"
#include "./WS2812/ws2812b.h"
#include "./WS2812/ws2812binterface.h"
#include "ucp.h"
//  PID = Proportional Integral Derivative
#define RPM_THRESHOLD_MAX   200//合理的RPM最大值 = Maximum reasonable RPM
#define RPM_THRESHOLD_MIN   -200//合理的RPM最小值 = Minimum reasonable RPM
#define KEY_LONG_PRESS_TIME 5000//开关机时间，单位ms = Power on/off press time, in ms
#define SYS_START_UP_TIME 1500//开机后开始识别按键的时间，单位ms = Time after startup before recognizing key presses, in ms
#define SECOND 1000
#define PER 10//定时周期100ms = Timer period 100 ms
#define RPP 11//每圈的脉冲数 = Pulses per revolution
#define REDUCTION_RATIO 90//减速比 = Gear reduction ratio
#define LOCKED_ROTOR_TIME 8000/PER	//单位ms = Locked rotor time, in ms
#define OVER_LOADER_TIME 16000/PER	//单位ms = Overload time, in ms
#define NOR_SPEED_OVERLOAD_RPM 50	//正常速度RPM = Normal speed RPM
#define FAST_SPEED_OVERLOAD_RPM 100	//最快速度RPM = Fastest speed RPM

//变加减速S型曲线参数 = Variable acceleration/deceleration S-curve parameters
#define S_START 0
#define S_END 50000
#define S_STEP 100

#define FILTER_SIZE 50
#define V_FILTER_SIZE 20 // 滑动滤波器的窗口大小 = Moving average filter window size
#define C_FILTER_SIZE 10 // 滑动滤波器的窗口大小 = Moving average filter window size
#define P_FILTER_SIZE 10 // 滑动滤波器的窗口大小 = Moving average filter window size
#define T_FILTER_SIZE 50 // 滑动滤波器的窗口大小(温度) = Moving average filter window size (temperature)
#define FULLPWR  12.00   //  满电电压，放大100倍 = Full battery voltage, scaled by 100
#define CUTPWR  800    //  截止电压，放大100倍 = Cutoff voltage, scaled by 100
#define LOWPWR  9.60    //  最低电压，放大100倍 = Minimum voltage, scaled by 100
#define PERIOD 50000//周期，单位ns，频率20KHz。很关键的参数，调试好后尽量不动50000 = Period, in ns, frequency 20 kHz. Very critical parameter — once tuned, try not to change 50000

typedef struct robot_state_t
{
			int16_t rpm [ 4 ];
			uint16_t battery;   //建议有无效值 = Suggest having an invalid value (for error checking)
			float voltage;  //电压V，放大100倍 = Voltage (V), scaled by 100
			float current;  //电流A，放大100倍 = Current (A), scaled by 100
			float power;    //功率W = Power (W)
			uint32_t over_loader_num;  //过载次数 = Number of overload events
			uint32_t locked_rotor_num;  //堵转次数 = Number of locked rotor events
			uint32_t rs485_crcerr_num;  //RS485丢包次数 = Number of RS485 packet loss (CRC errors)
			uint8_t lamp;
			uint8_t tof;
			int16_t speed;
			int16_t steer;
			uint8_t key;
			uint8_t pwr;    //外设电路供电开关 = Peripheral circuit power switch
			uint8_t break_mode;  //刹车模式 = Brake mode
			uint8_t break_status;
			system_state_t status;  //MCU系统状态 0：充电中  1：充电完毕  2：系统初始状态 3：系统运行状态 4：系统关机状态 = 
                                //MCU system state: 
                                // 0: charging
                                // 1: charging complete
                                // 2: system initial state
                                // 3: system running state
                                // 4: system shutdown state
			ucp_state_e net_led_status; //头部联网状态示灯 = Head network status indicator LED

} robot_state_t;
typedef struct
{
      float buffer [ FILTER_SIZE ];  // 存储样本的缓冲区 = Buffer to store samples
      rt_int32_t index;                  // 当前样本在缓冲区中的索引 = Current sample index in the buffer
      rt_int32_t count;                  // 缓冲区中当前存储的样本数量 = Current number of samples stored in the buffer
      float sum;                // 缓冲区中样本的总和，用于快速计算平均值 = Sum of samples in the buffer (for fast average calculation)
} SlidingFilter;
//宏定义系统RGB状态灯的引脚 = Macro definition of system RGB status LED pins
#define LED_SYS_R_PIN GET_PIN(C, 4)
#define LED_SYS_G_PIN GET_PIN(A, 7)
#define LED_SYS_B_PIN GET_PIN(C, 5)

//电机PID驱动(打开宏PID_OFF关闭PID) = Motor PID drive (define PID_OFF macro to disable PID)
//#define PID_OFF
//定义4路电机引脚 = Define 4 motor control pins
#define PWM_DEV_NAME1 "pwm1"
#define PWM_DEV_NAME9 "pwm9"
#define PWM_DEV_NAME10 "pwm10"
#define PWM_DEV_NAME11 "pwm11"
#define MOTOR_LF_IN 4	//左后电机的PWM引脚位TIM1的CH4 = Left-rear motor PWM pin at TIM1 Channel 4
#define MOTOR_LB_IN 2	//左后电机的PWM引脚位TIM1的CH2 = Left-rear motor PWM pin at TIM1 Channel 2
#define MOTOR_RF_IN 1	//左后电机的PWM引脚位TIM9的CH1 = Right-front motor PWM pin at TIM9 Channel 1
#define MOTOR_RB_IN 1	//左后电机的PWM引脚位TIM11的CH1 = Right-rear motor PWM pin at TIM11 Channel 1

#define MOTOR_L_IN 4    //左电机的PWM引脚位TIM1的CH4 = Left motor PWM pin at TIM1 Channel 4
#define MOTOR_R_IN 2    //右电机的PWM引脚位TIM1的CH2 = Right motor PWM pin at TIM1 Channel 2

#define MOTOR_LF_BREAK 3//左前刹车TIM1_CH3 = Left-front brake at TIM1 Channel 3
#define MOTOR_LB_BREAK 1//左前刹车TIM1_CH1 = 
#define MOTOR_RF_BREAK 2//左前刹车TIM9_CH2 = 
#define MOTOR_RB_BREAK 1//左前刹车TIM10_CH1 =
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

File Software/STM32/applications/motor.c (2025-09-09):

#include "main.h"

#define DBG_TAG "MOTOR"
#define DBG_LVL DBG_LOG
#include <rtdbg.h>
#include "board.h"
#include "state.h"
#include "pid.h"
#include "imu.h"

// PWM device handles (for motor control)
struct rt_device_pwm *pwm_dev1;
struct rt_device_pwm *pwm_dev9;
struct rt_device_pwm *pwm_dev10;
struct rt_device_pwm *pwm_dev11;

//#define PWM_DEV_NAME1 "pwm1"
//#define PWM_DEV_NAME9 "pwm9"
//#define PWM_DEV_NAME10 "pwm10"
//#define PWM_DEV_NAME11 "pwm11"

//#define MOTOR_LF_IN 4	// 左后电机的PWM引脚位TIM1的CH4
//                      // Left-rear motor PWM pin is TIM1 CH4
//#define MOTOR_LB_IN 2	// 左后电机的PWM引脚位TIM1的CH2
//                      // Left-back motor PWM pin is TIM1 CH2
//#define MOTOR_RF_IN 1	// 左后电机的PWM引脚位TIM9的CH1
//                      // Right-front motor PWM pin is TIM9 CH1
//#define MOTOR_RB_IN 1	// 左后电机的PWM引脚位TIM11的CH1
//                      // Right-back motor PWM pin is TIM11 CH1
//
//#define MOTOR_LF_BREAK 3 // 左前刹车 TIM1_CH3
//                        // Left-front brake signal on TIM1 CH3
//#define MOTOR_LB_BREAK 1 // 左前刹车 TIM1_CH1
//                        // Left-back brake signal on TIM1 CH1
//#define MOTOR_RF_BREAK 2 // 左前刹车 TIM9_CH3
//                        // Right-front brake signal on TIM9 CH3
//#define MOTOR_RB_BREAK 1 // 左前刹车 TIM10_CH1
//                        // Right-back brake signal on TIM10 CH1
//
//#define MOTOR_DIR_LF GET_PIN(A, 0)	 // 左前电机方向引脚
//                                      // Left-front motor direction pin
//#define MOTOR_DIR_LB GET_PIN(D, 12)	 // 左后电机方向引脚
//                                      // Left-back motor direction pin
//#define MOTOR_DIR_RF GET_PIN(B, 4)	 // 右前电机方向引脚
//                                      // Right-front motor direction pin
//#define MOTOR_DIR_RB GET_PIN(A, 15)	 // 右后电机方向引脚
//                                      // Right-back motor direction pin
//
////#define MOTOR_BREAK_LF GET_PIN(E, 13)
////#define MOTOR_BREAK_LB GET_PIN(E, 9)
////#define MOTOR_BREAK_RF GET_PIN(E, 6)
////#define MOTOR_BREAK_RB GET_PIN(B, 8)
//
//#define MOTOR_FG_LF GET_PIN(A, 1)     // 左前 FG 信号 (speed feedback pin)
//#define MOTOR_FG_LB GET_PIN(D, 13)    // 左后 FG 信号
//#define MOTOR_FG_RF GET_PIN(B, 5)     // 右前 FG 信号
//#define MOTOR_FG_RB GET_PIN(B, 3)     // 右后 FG 信号
//
//#define MOTOR_VIN_ENABLE_PIN GET_PIN(E, 4) // 电机电源使能引脚
//                                          // Motor VIN enable pin

//#define PERIOD 50000 // 周期，单位ns，频率20KHz。很关键的参数，调试好后尽量不动
//                    // Period in ns, frequency 20 kHz. Critical parameter, avoid changing after tuning
//#define PERIOD 10500 // 周期，单位ns，频率100KHz。很关键的参数，调试好后尽量不动
//#define PERIOD 16250 // 周期，单位ns，频率10KHz。很关键的参数，调试好后尽量不动
//#define PERIOD 40000 // 周期，单位ns，频率25KHz。很关键的参数，调试好后尽量不动

// Encoder device names for each wheel
#define ENCODER_LF_DEV "pulse5"
#define ENCODER_LB_DEV "pulse4"
#define ENCODER_RF_DEV "pulse3"
#define ENCODER_RB_DEV "pulse2"

// 定时器设备句柄 - timer device handles for encoder inputs
rt_device_t hw_dev_2,hw_dev_3,hw_dev_4,hw_dev_5 = RT_NULL;

pid_motor_control pid_motor;  // Motor PID control state
speed_pid speed_pid_s;        // Speed PID controller state

// Structure to represent one motor (PWM + encoder)
typedef struct robot_motor_t
{
	  struct rt_device_pwm *pwm_dev;                 // PWM device handle
	  struct rt_pulse_encoder_device *encoder_dev;   // Encoder device handle
} robot_motor_t;

// Motor instances for left-front, left-back, right-front, right-back
struct robot_motor_t motor_lf , motor_lb , motor_rf , motor_rb;

// Motor direction enumeration
typedef enum motor_direction_t
{
	  STOP, FORWARD, BACKWARD, LEFT, RIGHT,
} motor_direction_t;

// Motor state: PWM duty cycle + direction
typedef struct motor_state_t
{
	  uint8_t duty_l;             // Left motor duty cycle
	  uint8_t duty_r;             // Right motor duty cycle
	  motor_direction_t dir;      // Motion direction
} motor_state_t;

motor_state_t motor_state;       // Current motor state

// Exponential smoothing filter variables
float smoothedValue_speed = 0.0;
float smoothedValue_angular = 0.0;
float prevSmoothedValue_speed = 0.0;
float prevSmoothedValue_angular = 0.0;
float weight_speed = 0.25;   // Smoothing weight (0.25 for 24V, 0.3 for 12V)
float weight_angular = 0.55; // Smoothing weight for angular velocity

// Simple exponential smoothing filter function
float filter ( float rawValue , float w , float prevValue )
{
	  float result = w * rawValue + (1.0 - w) * prevValue;
	  return result;
}

extern u_int8_t count_state;
float coeff_angular = 0.7;  // Angular coefficient for control scaling

// Initialize motor control pins (direction, enable, etc.)
void motor_init_pin ( void )
{
	  // 初始化电机方向控制相关引脚
	  // Initialize motor direction control pins
//	  rt_pin_mode ( MOTOR_DIR_LF , PIN_MODE_OUTPUT );
//	  rt_pin_mode ( MOTOR_DIR_LB , PIN_MODE_OUTPUT );
//	  rt_pin_mode ( MOTOR_DIR_RF , PIN_MODE_OUTPUT );
//	  rt_pin_mode ( MOTOR_DIR_RB , PIN_MODE_OUTPUT );

      rt_pin_mode( MOTOR_DIR_L , PIN_MODE_OUTPUT ); // Left wheel direction
      rt_pin_mode( MOTOR_DIR_R , PIN_MODE_OUTPUT ); // Right wheel direction

//	  rt_pin_mode ( MOTOR_VIN_ENABLE_PIN , PIN_MODE_OUTPUT ); // 电机供电使能引脚 - motor VIN enable

	  // 初始化默认的电机方向状态
	  // Initialize default motor direction state
	  // 方向控制——默认前进方向
	  // Direction control: default set to "forward"
//	  rt_pin_write ( MOTOR_DIR_LF , PIN_LOW );   // 左前
//	  rt_pin_write ( MOTOR_DIR_LB , PIN_LOW );   // 左后
//	  rt_pin_write ( MOTOR_DIR_RF , PIN_HIGH );  // 右前
//	  rt_pin_write ( MOTOR_DIR_RB , PIN_HIGH );  // 右后
	  rt_pin_write ( MOTOR_DIR_L , PIN_LOW );   // 左轮 (forward)
	  rt_pin_write ( MOTOR_DIR_R , PIN_HIGH );  // 右轮 (forward)

	  // 初始化默认的电机供电使能状态
	  // Initialize default motor power enable state
	  // 供电使能控制——默认使能
	  // Power enable control: default ON
//	  rt_pin_write ( MOTOR_VIN_ENABLE_PIN , PIN_LOW );
//	  rt_thread_delay ( 1000 );
//	  rt_pin_write ( MOTOR_VIN_ENABLE_PIN , PIN_HIGH );
}
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

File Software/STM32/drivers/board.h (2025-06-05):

/*
 * Copyright (c) 2006-2024, RT-Thread Development Team
 *
 * SPDX-License-Identifier: Apache-2.0
 *
 * Change Logs:
 * Date           Author       Notes
 * 2024-02-29     RealThread   first version
 */

#ifndef __BOARD_H__
#define __BOARD_H__

#include <stm32f4xx.h>
#include <drv_common.h>
//#define WHEELTEC

#ifdef __cplusplus
extern "C"
{
#endif

//#define APP_VERSION 14	//自增内容,使用的是V5.1
#define APP_VERSION 38	//自增内容,使用的是V5.2，V5.2的版本为20+，V6.0版本，则为30+

/*-------------------------- CHIP CONFIG BEGIN --------------------------*/

#define CHIP_FAMILY_STM32
#define CHIP_SERIES_STM32F4
#define CHIP_NAME_STM32F407VE

/*-------------------------- CHIP CONFIG END --------------------------*/

/*-------------------------- ROM/RAM CONFIG BEGIN --------------------------*/

#define ROM_START              ((uint32_t)0x08000000)
#define ROM_SIZE               (512 * 1024)
#define ROM_END                ((uint32_t)(ROM_START + ROM_SIZE))

#define RAM_START              (0x20000000)
#define RAM_SIZE               (128 * 1024)
#define RAM_END                (RAM_START + RAM_SIZE)

/*-------------------------- ROM/RAM CONFIG END --------------------------*/

/*-------------------------- CLOCK CONFIG BEGIN --------------------------*/

#define BSP_CLOCK_SOURCE                  ("HSE")
#define BSP_CLOCK_SOURCE_FREQ_MHZ         ((int32_t)0)
#define BSP_CLOCK_SYSTEM_FREQ_MHZ         ((int32_t)168)

/*-------------------------- CLOCK CONFIG END --------------------------*/

/*-------------------------- UART CONFIG BEGIN --------------------------*/

/** After configuring corresponding UART or UART DMA, you can use it.
 *
 * STEP 1, define macro define related to the serial port opening based on the serial port number
 *                 such as     #define BSP_USING_UART1
 *
 * STEP 2, according to the corresponding pin of serial port, define the related serial port information macro
 *                 such as     #define BSP_UART1_TX_PIN       "PA9"
 *                             #define BSP_UART1_RX_PIN       "PA10"
 *
 * STEP 3, if you want using SERIAL DMA, you must open it in the RT-Thread Settings.
 *                 RT-Thread Setting -> Components -> Device Drivers -> Serial Device Drivers -> Enable Serial DMA Mode
 *
 * STEP 4, according to serial port number to define serial port tx/rx DMA function in the board.h file
 *                 such as     #define BSP_UART1_RX_USING_DMA
 *
 */

#define BSP_USING_UART1
//#define BSP_UART1_RX_USING_DMA
#define BSP_UART1_TX_PIN       "PA9"
#define BSP_UART1_RX_PIN       "PA10"

#define BSP_USING_UART2
//#define BSP_UART3_RX_USING_DMA
#define BSP_UART2_TX_PIN       "PD5"
#define BSP_UART2_RX_PIN       "PD6"

#define BSP_USING_UART3
//#define BSP_UART3_RX_USING_DMA
#define BSP_UART3_TX_PIN       "PC10"
#define BSP_UART3_RX_PIN       "PC11"
#define BSP_UART3_RX_USING_DMA

#define BSP_USING_UART5
//#define BSP_UART5_RX_USING_DMA
#define BSP_UART5_TX_PIN       "PC12"
#define BSP_UART5_RX_PIN       "PD2"

/*-------------------------- UART CONFIG END --------------------------*/

/*-------------------------- I2C CONFIG BEGIN --------------------------*/

/** if you want to use i2c bus(soft simulate) you can use the following instructions.
 *
 * STEP 1, open i2c driver framework(soft simulate) support in the RT-Thread Settings file
 *
 * STEP 2, define macro related to the i2c bus
 *                 such as     #define BSP_USING_I2C1
 *
 * STEP 3, according to the corresponding pin of i2c port, modify the related i2c port and pin information
 *                 such as     #define BSP_I2C1_SCL_PIN    GET_PIN(port, pin)   ->   GET_PIN(C, 11)
 *                             #define BSP_I2C1_SDA_PIN    GET_PIN(port, pin)   ->   GET_PIN(C, 12)
 */

#define BSP_USING_I2C1
#ifdef BSP_USING_I2C1
#define BSP_I2C1_SCL_PIN    GET_PIN(B, 6) //GET_PIN(B, 6)
#define BSP_I2C1_SDA_PIN    GET_PIN(B, 7) //GET_PIN(B, 7)
#endif

#define BSP_USING_I2C2
#ifdef BSP_USING_I2C2
#define BSP_I2C2_SCL_PIN    GET_PIN(B, 10)
#define BSP_I2C2_SDA_PIN    GET_PIN(B, 11)
#endif

/*-------------------------- I2C CONFIG END --------------------------*/

/*-------------------------- SPI CONFIG BEGIN --------------------------*/

/** if you want to use spi bus you can use the following instructions.
 *
 * STEP 1, open spi driver framework support in the RT-Thread Settings file
 *
 * STEP 2, define macro related to the spi bus
 *                 such as     #define BSP_USING_SPI1
 *
 * STEP 3, copy your spi init function from stm32xxxx_hal_msp.c generated by stm32cubemx to the end of board.c file
 *                 such as     void HAL_SPI_MspInit(SPI_HandleTypeDef* hspi)
 *
 * STEP 4, modify your stm32xxxx_hal_config.h file to support spi peripherals. define macro related to the peripherals
 *                 such as     #define HAL_SPI_MODULE_ENABLED
 */

/*#define BSP_USING_SPI1*/
#define BSP_USING_SPI2
/*#define BSP_USING_SPI3*/

/*-------------------------- SPI CONFIG END --------------------------*/
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

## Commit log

2025-06-05 Add RT-Thread initial project(v6.38) to projects/earth-rover-rtthread
    [kconfig-language.txt, kconfig.txt]
2025-06-05 Add 3dp files
    [back_cover.stp, back_top.stp, body.stp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]
2025-06-05 PCB image
2025-06-23 upload doc: STM32 control protocol
2025-08-01 schematic and gerber
2025-10-02 Add camera example and media libs
2025-10-13 Add 3D model with Git LFS
    [v6-mini+.stp]
